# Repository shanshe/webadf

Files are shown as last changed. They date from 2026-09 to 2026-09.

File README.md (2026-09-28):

# webadf

An Amiga disk library that puts a disk in a real Amiga's floppy drive over WiFi.

Two halves that work together:

- **A web app** for keeping Amiga disk images. Upload them, have them identified
  against TOSEC, OpenRetro and Demozoo, organise them into collections, browse and
  edit the files inside a disk, and rewind a disk to any earlier version.
- **A drive replacement.** An RP2350 board plugs into the Amiga's floppy connector,
  behaves like a DD or HD floppy drive, and plays whichever disk you pick in the web app.
  When the Amiga saves, the changes go back to the library.

Pick a disk in the browser, or tap its NFC tag on the drive, and the Amiga reads it.
Workbench 3.1 boots from the board, games load, and saves made on the Amiga show up
in the web app as new versions of the disk.

The rev B board: floppy header J1 on the left, buzzer and OLED in the middle, the Pico Plus 2 W module on the right

*Rev B, designed by Shanshe: 34-pin floppy header, floppy power connector, OLED
display, buzzer, a 4-pin header (J4), and a Pimoroni Pico Plus 2 W.
The KiCad project is in `wifi-floppy/hardware/`; check it with `pnpm hw:verify` before
ordering. The current bench board is rev A2.*

## Features

### Library

- Upload `.adf`, `.adz`, `.dms` and `.hfe`; drop `.lha` and `.zip` archives onto a disk
  to pick files out of them.
- HD (1.76 MB) ADFs are recognised and tagged HD, and are disks like any other: browsed
  and edited in the browser, with full history. Blank HD disks can be made from the
  New disk panel.
- Each unique disk is stored once, however many times it is uploaded.
- Disks are identified against TOSEC, OpenRetro and Demozoo, and grouped into titles
  with cover art, screenshots, publisher, year and type.
- Collections, search as you type, and a layout that works on a phone.
- Create a blank formatted disk: 880 KB or 1.76 MB, OFS or FFS.
- Download any disk as an ADF.

### Inside a disk

- Browse the AmigaDOS filesystem in the browser: files, folders, free space.
- Add, rename, move and delete files and folders; drop a folder from your computer
  onto a disk; drag entries between folders.
- Every change is a new version. The history panel shows what changed in each
  version, lets you browse any old version, and restores one as a new version.
- HFE images (including long-track formats such as Turrican's) play read-only and can
  be extracted to an ADF when every sector decodes.

### The drive

- Set up from a phone: the board opens a WiFi setup page, you enter your network and
  a pairing code from the web app, and it joins your library.
- Mount and eject from the web app, from the drive chips in the header, or by
  tapping an NFC tag.
- Reads and writes on a real Amiga. Saves reach the library as new disk versions,
  including saves made while the board was offline.
- Works as DF0 or alongside a second drive as DF1.
- Plays HD disks: the board tells the Amiga it is an HD drive while an HD disk is in.
  Needs Kickstart 3.0 or later. Playing needs firmware 1.4.1 or later (the web app
  refuses to mount an HD disk on older firmware and says so); saving to an HD disk
  needs 1.5.0 (1.4.x keeps HD write-protected on the board whatever the web app
  says).
- Write protection can be switched from the web app while the disk is in the drive.
- OLED status display: WiFi strength, what it is doing, the disk's name and the
  current track. An activity LED blinks on reads.
- Updates its own firmware from the web app. Releases are signed, a failed update
  falls back to the previous firmware, and the board never updates while a disk is
  in the drive.

### NFC tags

- Tap a tag on the drive to mount its disk. Tapping another tag swaps disks; tapping
  the one already in the drive does nothing.
- Write any disk to a tag from its library card or game page: click the NFC icon,
  tap a tag on the drive, and the result appears in the browser.
- A tag only ever mounts disks from your own library.
- Reader: HW-147C (Si512), on the board's I2C bus next to the OLED.

## How it works

An Amiga floppy drive does not deliver blocks. It hands Paula a raw magnetic flux
stream and the Amiga decodes MFM in software, so a drive emulator has to produce flux
at the right rate, continuously, while the disk spins.

```
  browser  ──mount──▶  web app  ──encodes ADF → MFM──▶  device  ──flux──▶  Amiga
     ▲                    │                                │
     └──── new version ◀──┴── Postgres + blobs     RP2350 + 8 MB PSRAM ◀── NFC tag
```

The server encodes a 901,120-byte ADF into 2,027,536 bytes of Amiga MFM and the board
streams it: PIO emits 2 µs bitcells, DMA restarts each revolution and raises INDEX,
giving 300 rpm. The whole disk lives in PSRAM, so a seek is answered immediately
instead of over the network. The board streams flux rather than ADFs, which lets
flux formats such as HFE use the same path.

An HD disk is the exception. The server sends the board the ADF itself (a small
WFAD header, then 1,802,240 bytes), and the board encodes each track to MFM as the
head reaches it, in about 4 ms, well inside the head's settle time. A PIO program
answers the Amiga's drive-ID read on RDY with the HD ID while an HD disk is mounted.
When the Amiga saves to an HD disk, the board checks all 22 sectors of the written
track, keeps them as ADF bytes, and uploads those bytes as they are.

When the Amiga writes, the board decodes the written tracks, uploads them, and the
server records them as a new version of the disk. Versions are stored as sector
deltas.

## Status

| | |
|---|---|
| Web app: library, collections, identification, search | live |
| Upload `.adf` `.adz` `.dms` `.hfe`; `.lha`/`.zip` onto a disk | live |
| File editing inside a disk, blank disks, drag and drop | live |
| Disk history: browse and restore any version | live, restore verified on hardware |
| Device: setup portal, WiFi, TLS, pairing | verified on hardware |
| Mount and eject from the browser and the drive chips | verified on hardware |
| Reading on a real Amiga (Workbench 3.1, games) | verified on hardware |
| Writing on a real Amiga, saves reach the library | verified on hardware |
| Second drive (DF1) alongside the board | verified on hardware |
| HFE, including long-track (Turrican) | verified on hardware; weak-bit titles not yet tested |
| HD disks, read-only (Kickstart 3.0+) | verified on hardware (firmware 1.4.1, Kickstart 3.1) |
| HD disks: Amiga saves, history, browser editing, blank HD disks | built and host-tested (firmware 1.5.0, not yet published); bench checklist owed (HANDOFF 3ao) |
| Firmware updates from the web app | verified on hardware (current: 1.3.1; 1.4.0 built, not yet published) |
| NFC: tap to mount, write tags from the web | verified on hardware |
| Rev B board | in design (Shanshe) |

## Repository

| Path | What |
|---|---|
| `src/` | the Next.js app |
| `src/lib/adfmfm/` | ADF ⇄ Amiga MFM encoder, verified against Greaseweazle |
| `src/lib/adffs/` | AmigaDOS filesystem reader/writer (OFS/FFS) |
| `src/lib/archive/` | `.lha`, `.zip` and `.dms` decoders, all browser-side |
| `src/lib/hfe/` | HFE parsing, conversion for the board, ADF extraction |
| `src/lib/disk-history/` | sector deltas and the version chain behind history and restore |
| `src/lib/nfc/` | NFC tap and tag-writing rules and storage |
| `wifi-floppy/firmware/` | the RP2350 firmware (pico-sdk ≥ 2.3.0) |
| `wifi-floppy/hardware/` | the board (KiCad) |
| `docs/superpowers/specs/` | design specs, one per feature |
| `HANDOFF.md` | the engineering log: decisions, measurements, bench results |

## Running it

```bash
pnpm install
pnpm dev                  # needs .env.local: DATABASE_URL, BLOB_READ_WRITE_TOKEN,
                          # BETTER_AUTH_SECRET, BETTER_AUTH_URL
pnpm test                 # vitest, pure logic
pnpm e2e                  # playwright, against a real database
```

Firmware:

```bash
export PICO_SDK_PATH=/path/to/pico-sdk        # tag 2.3.0 or later
pnpm firmware:build
pnpm firmware:test                            # host tests, no board needed
pnpm firmware:publish --dry-run               # sign and register a release
```

Write a disk to an NFC tag from the command line:

```bash
pnpm nfc:write "Turrican II disk 1"           # then tap a tag on the drive
```

The setup access point uses the password **`wififloppy`** by default. Set
`PORTAL_AP_PASSWORD` at build time to change it. The pairing code from the web app is
what authorises a board to join a library.

Every push that touches the firmware is built by
[`.github/workflows/firmware.yml`](.github/workflows/firmware.yml), which runs the host
tests and publishes a `.uf2` with a `manifest.json` (version, commit, size, SHA-256).

## Verification

Each layer that talks to hardware or to an undocumented format is checked against an
independent implementation:

| | checked against |
|---|---|
| `pnpm adfmfm:diff` | Greaseweazle's `amigados` codec |
| `pnpm adffs:verify` | `xdftool` |
| `pnpm lha:verify` | the real `lha` binary |
| `pnpm dms:verify` | xDMS, the implementation ours was ported from |

## Licence

- **Software** (the web app, scripts and the wifi-floppy firmware source): [MIT](LICENSE).
- **Hardware** (`wifi-floppy/hardware/`, the board design): [CERN-OHL-P-2.0](wifi-floppy/hardware/LICENSE), the
  permissive open-hardware licence, so anyone can build, modify and sell their own boards. The rev B PCB layout is
  Shanshe's work, licensed this way with Shanshe's agreement; see
  [wifi-floppy/hardware/NOTICE.md](wifi-floppy/hardware/NOTICE.md).
- **Third-party code, the libraries in the firmware image, and acknowledgements**: see
  [THIRD-PARTY-NOTICES.md](THIRD-PARTY-NOTICES.md). The Wi-Fi driver bundled with the Pico SDK is licensed for use
  on Raspberry Pi chips (which this board is).

This project builds on Nano-Tek, OpenFlops, Keir Fraser's FlashFloppy and Greaseweazle, and the other work credited
in the notices file.

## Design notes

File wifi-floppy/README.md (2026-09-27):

# WiFi Floppy Emulator (Amiga) — Pico 2 W

Gotek-style drive replacement that streams pre-encoded MFM tracks over
WiFi from your ADF webservice instead of reading a USB stick.

## Contents
- `hardware/schematic.svg` — full schematic (net names match the PCB)
- `hardware/wifi_floppy.kicad_pcb` — placed **and routed** 2-layer board,
  45°-only corners, B.Cu ground pour. Open directly in KiCad 7/8 and
  press `B` to refill the zone.
- `hardware/generate_pcb.py` — the generator that produced the board,
  including a DRC-lite checker (crossings, clearance ≥0.15 mm, 45° rule).
  Currently passes with 0 violations.
- `firmware/` — pico-sdk project (RP2350 / `PICO_BOARD=pimoroni_pico_plus2_w_rp2350`,
  pico-sdk >= 2.3.0 required — see "Firmware build requirements" below).

## Design
- **J1** 34-pin, Amiga internal pinout: pin 2 = /DSKCHG, pin 34 = /RDY
  (unlike PC drives where 34 is DSKCHG).
- **U2 74LVC541A** buffers all host-driven lines into the Pico
  (3.3 V part, 5 V-tolerant inputs). J1→A1..A8→GP2..GP9 are mapped in
  physical order, so the input routing is completely crossing-free.
- **Q1–Q6 BSS138** give open-drain outputs. They invert: **GPIO high =
  bus line pulled low**. Firmware and the PIO program already account
  for this (`OUT_ASSERT`).
- **Power**: 5 V from the Berg connector through D1 (SS14) into VSYS.
  Safe to co-power over USB while bench testing.
- PIO `flux_out` emits 2 µs bitcells (8 PIO cycles @ 4 MHz, clkdiv 37.5
  from 150 MHz), 750 ns read pulses; DMA restarts per revolution and
  raises a ~2 ms INDEX pulse at the wrap → exactly 300 rpm timing.
- 16-track LRU cache (~205 KB) + neighbour prefetch; a track is ~12.7 KB
  so a LAN fetch lands well inside a seek's settle time.

## Track server protocol — SUPERSEDED

**This section describes a protocol the firmware no longer speaks.** `http_fetch.c`,
which implemented `GET /tracks/<n>`, was deleted in plan 4a. The real device contract is
`GET /api/device/poll` (long-poll for desired state), `GET /api/device/image/<sha256>`
(the whole disk as a `WFMF` container, format defined in `image_loader.c`), and
`POST /api/device/status`. See `INTEGRATION.md` and
`docs/superpowers/specs/2026-08-29-device-plane-disk-change-design.md` §10 for the actual
contract. Kept below only as a historical note; do not implement against it.

```
GET /tracks/<n>        n = cyl*2 + side  (0..159)
 -> 200, body = [u32 LE bit_count][raw MFM bytes]
POST /tracks/<n>       (write-back, not implemented yet)
```
Encode server-side (ADF → Amiga MFM incl. 0x4489 syncs, odd/even split);
the firmware just plays bits. Suggested next step for the webservice.

## DSKCHG / RDY
`src/dskchg.c` re-implements FlashFloppy's Amiga-interface behaviour
(chgrst=step semantics, motor-edge drive-ID shifter, spin-up delay).
It's a from-scratch implementation of the observable behaviour, not a
code port. FlashFloppy is Keir Fraser's (https://github.com/keirf/flashfloppy,
Unlicense) and is credited in ../THIRD-PARTY-NOTICES.md.

## Firmware build requirements

- **pico-sdk >= 2.3.0.** `hardware_psram` (and this board's
  `PICO_PSRAM_CS_PIN`/`PICO_PSRAM_SIZE_BYTES` board-header support) landed in
  pico-sdk PR #2919, after the 2.2.0 release; 2.3.0 is the first tag that has
  it. `CMakeLists.txt` checks `PICO_SDK_VERSION_STRING` and fails the
  configure step with an explanation if `PICO_SDK_PATH` points at anything
  older.
- **`brew install arm-none-eabi-gcc` is not sufficient** — that formula ships
  GCC and libgcc but no newlib, so linking fails with `cannot find -lg`/`-lc`
  on the very first target. Use the official ARM GNU Toolchain instead (the
  `gcc-arm-embedded` cask, or the equivalent tarball from
  developer.arm.com/downloads/-/arm-gnu-toolchain-downloads) and make sure
  its `bin/` is on `PATH` ahead of any homebrew `arm-none-eabi-*` shims.
- **`PORTAL_AP_PASSWORD` must be set in the environment (plan 4b).** It becomes the WPA2
  PSK for the provisioning access point (see "Provisioning a board" below); CMake's
  configure step fails on purpose if it is unset or empty, because an invalid WPA2 PSK
  cannot be reported back to a console-less board at runtime. The full build command:

  ```bash
  export PATH="/Applications/ArmGNUToolchain/15.3.rel1/arm-none-eabi/bin:$PATH"
  export PORTAL_AP_PASSWORD=<your AP password>
  pnpm firmware:build
  ```

## Provisioning a board (plan 4b)

**Steps 1-3 are verified on hardware as of 2026-09-10; steps 4-5 are not.** The AP
comes up, iOS raises the sign-in sheet on its own, and the form renders at
192.168.4.1. Everything from pressing Save onwards — teardown, association,
registration — has still only ever run against the host suite. See "Honest caveats"
below.

A board with no WiFi credentials stored in flash — or one that has just failed to associate
three times in a row — raises its own WPA2 access point named `wifi-floppy-XXXX`, where
`XXXX` is the last two octets of the board's MAC address (so several boards on a bench stay
distinguishable). To provision it:

1. **Mint a pairing code in webadf.** From the web app, generate a device pairing code for
   the board (single-use, 10-minute TTL — if it expires before step 4, generate a new one).
2. **Join `wifi-floppy-XXXX`** from your phone or laptop, using the WPA2 password baked into
   that board's firmware image at build time (`PORTAL_AP_PASSWORD`, above — whoever built
   the firmware knows it).
3. **Open any page** in a browser on that device. The board's DNS responder answers every
   query with its own address and the HTTP server redirects every path to `/`, so a phone's
   captive-portal probe should bring the config form up on its own; if it does not, browse to
   `http://192.168.4.1/` directly.
4. **Enter three fields**: your real WiFi network's SSID, its password, and the pairing code
   from step 1. Submitting does not commit anything yet — the board drops its own AP,
   attempts to associate with what you typed, and only writes the credentials to flash on
   success. Your phone will briefly lose the `wifi-floppy-XXXX` network while this happens.
5. **On success**, the board joins your real network and proceeds to register with webadf
   using the pairing code; the AP does not come back. **On failure** (wrong password, or the
   network was not found — the form distinguishes the two), the AP returns with the reason
   and the form is ready to try again; re-enter all three fields, since none are echoed back.

**Recovery without reflashing.** If webadf later reports the board's token as revoked or the
device row is deleted, the board erases its stored token and returns to step 1 automatically
— generate a fresh pairing code and repeat steps 2–5. The same is true of a rejected
(expired or already-used) pairing code: the board returns to the portal rather than retrying
the dead code forever.

## Watching the log

```bash
tio /dev/cu.usbmodem*          # brew install tio; it reconnects across reboots
```

Output looks like this — uptime in seconds.milliseconds, then which core:

```
[    0.002] c0 wifi-floppy boot: pimoroni_pico_plus2_w_rp2350
[    0.481] c1 radio up (RM2)
[    0.494] c1 portal: raising AP
[   34.117] c0 MOTOR        a=1 b=0
[   34.119] c0 SEL          a=1 b=0
[   34.226] c0 STEP         a=1 b=0
[   34.229] c0 TRACK-SERVED a=2 b=101376
[   34.431] c0 INDEX        a=3168 b=0
```

Two entry points, and the difference is load-bearing. `wf_logf()` formats with
`vsnprintf` and is for core1 and core0's loop. `wf_trace()` takes an integer event code
and two integers — no formatting, no format string — so it is legal inside the flux DMA
handler, where a flash-resident string would not be. `wf_trace` is placed in SRAM with
`__not_in_flash_func` for the same reason `dma_irq` is.

**core0 drains, core1 only produces.** core0's service loop already sleeps 1 ms per
iteration and the bit-level work is PIO and DMA, so it has the slack to write to USB;
core1's loop blocks for tens of seconds inside a long-poll and would strand every core0
trace behind it. A useful consequence: a core1 hang still gets its last line out, which
is why `cyw43_arch_init` failing logs before it spins forever.

The ring holds 63 records (~7 KB of SRAM). When it fills it **drops newest and counts
them**, then prints `-- N record(s) dropped --` once the backlog clears. It never blocks
a producer: a logger that stalls the floppy service loop to report on the floppy service
loop would be worse than no logger. `PICO_STDIO_USB_STDOUT_TIMEOUT_US` is set to 1 ms in
`CMakeLists.txt`, against an SDK default of 500 ms, so an unattended USB port cannot
stall that loop either.

UART stdio stays off and must stay off: GP0 and GP1 are INDEX and CHNG on this board, so
enabling it would drive the floppy bus.

## Honest caveats
- **First run on real hardware: 2026-09-10.** A rev A2 board, partially populated
  (J1, J2 and U1 only), flashed with `wifi_floppy.uf2` and powered over USB. What that
  exercised, end to end, on real silicon:
  - the RP2350 boots the image, reaches `main()`, and launches core1
  - `cyw43_arch_init()` succeeds — the **RM2 radio works over SPI**, the single
    largest never-before-run piece
  - the AP comes up: `wifi-floppy-6A38`, WPA2-AES, SSID built from the chip's own MAC
  - **DHCP hands the phone an address, the DNS responder answers, and the HTTP server
    serves the form** at `192.168.4.1`
  - **iOS's captive-portal probe raises the sign-in sheet on its own** ("Wi-Fi med
    tilmelding"), which was explicitly on the unverified list
  - the page's `28:cd:c1:19:6a:38` and the SSID's `6A38` agree, so `main.c`'s
    `mac_address_string()` and `portal_net.c`'s SSID construction cross-check
  - no re-enumeration of the USB CDC device over several minutes: no crash loop

  **Still not run on hardware:** everything past pressing Save. AP teardown and the
  transition back to station mode, association with a real network, the confirmation
  page arriving before the AP drops, DHCP lease renewal after teardown, the 3-slot
  lease pool under real phone behaviour, Android's captive-portal probe, TLS, SNTP,
  device registration, and the whole floppy side — PIO cycle counts, DMA, PSRAM image
  load, bus timing — which remain desk-checked only. See
  `docs/decisions/2026-08-31-device-portal-rulings.md`'s hardware-only list for the
  full set, which plan 5 owns closing.
- **Console logging exists as of 2026-09-10 (`src/wf_log.c`), but has not itself run on
  hardware.** Before it, the firmware wrote nothing at all: `stdio_init_all()` brought up
  the CDC device so a port appeared and a terminal attached, but there was not one
  `printf` in `src/`, and listening returned zero bytes. See "Watching the log" below for
  how to use it. Host-tested (74 checks) and cross-built clean; every line it prints on a
  real board is still unobserved.
- It compiles (`pnpm firmware:build` produces `firmware/build/wifi_floppy.uf2`) and has
  a green host suite (`pnpm firmware:test`, 506 checks across 13 binaries, plain C under
  clang). Treat anything not covered by a host test or by the hardware run above as
  unverified.
- Write support is a skeleton: flux capture PIO exists, MFM decode and
  POST are TODO. WPROT is asserted by default until that lands.
- The board passes my generator's DRC-lite, but run real KiCad DRC and
  sanity-check footprints (Pico row spacing 17.78 mm, SOIC-20W, SOT-23)
  against your parts before ordering.
- No mounting holes; outline is a plain 96×62 mm rectangle. Reshape to
  3.5"-drive dimensions if you want it inside a Gotek/drive bay.
- Board is 2-layer; several signals ride the B.Cu plane, which slices
  the pour locally. Fine at 500 kHz MFM rates, but keep the pour filled.

## PSRAM revision (Pimoroni Pico Plus 2 W)

U1 is now specified as a **Pimoroni Pico Plus 2 W** (RP2350B, 16MB flash,
8MB PSRAM, RM2 radio). It keeps the Pico footprint and pinout, so the PCB is
unchanged electrically - only the module value differs.

PSRAM is the disk. The image is pulled in **one bulk transfer at mount**
(`image_loader.c`) and the floppy bus is served entirely from RAM after
that - the read path contains no network call at all.

| where | size | role |
|---|---|---|
| SRAM double buffer | ~26 KB | only DMA source for the flux PIO |
| PSRAM disk image | 2.03 MB | the whole disk, 160 x 13 KB slots |

**The route below is superseded** — the firmware fetches
`GET /api/device/image/<sha256>` (keyed by digest, not an integer id; see
`INTEGRATION.md` and disk-change spec §10), but the `WFMF` container body format
itself is current and matches `image_loader.c`:

    u32 magic 'WFMF'   u32 version=1   u32 track_count   u32 reserved
    per track: u32 bit_count, ceil(bits/8) bytes, padded to 4 bytes

RDY and CHNG stay deasserted until the whole image is in PSRAM, so a slow or
failed load looks like "no disk yet" to the Amiga rather than a drive that
stalls mid-track. A track missing from PSRAM is a fault, not a cache miss:
`track_cache_get()` returns NULL and nothing is streamed.

The loader parses the blob incrementally as TCP chunks arrive, writing
straight into PSRAM (a 2 MB image never fits in SRAM). It was tested on the
host against randomly-chunked input at real track sizes, plus malformed
input: oversized tracks and bad magic are rejected without overflowing a slot.

Notes / still to verify on hardware:

* **GP0/GP1 are the board's default UART pins** and carry INDEX and CHNG here.
  `pico_enable_stdio_uart(... 0)` is set; stdio goes out over USB. Do not
  re-enable UART stdio or it will drive the floppy bus.
* The flux DMA never reads PSRAM directly - a QMI cache miss contending with
  XIP can add latency at a 2 us bitcell. Tracks are copied PSRAM -> SRAM.
* **Antenna keepout position is still an assumption, and the PIM726 documents
  do not settle it.** A schematic carries no placement, and the "Pins and
  Dims" sheet's board illustration is not something to read a fab decision
  off. What the keepout currently claims, so it can be checked against a
  module in hand: it spans the module's full 21 mm width and the last 5.4 mm
  of its 51 mm length at the **non-USB end** - the pin 19-22 end, GP14-GP17.
  If the RM2's antenna is anywhere else, there is ground plane under it.
  Costs nothing to keep: GP14-GP17 are unused on this board, so the keepout
  is only wrong if it is in the wrong *place*, never merely expensive.
* ~~Confirm GP0-GP17 map to the same physical castellations on the RP2350B
  board as on the Pico 2 W.~~ **CONFIRMED 2026-09-09** against the PIM726
  schematic (sheet 3/3, "Output headers"). The Plus 2 W's header is the
  standard Pico header pin for pin: pin 1 = GP0 through pin 22 = GP17, with
  GND on 3/8/13/18/23. The only difference is that pins 6 and 7 are labelled
  `GP4_SDA` and `GP5_SCL` because they also feed the QW/ST connector - same
  GPIOs, alternate function. Every U1 signal this board uses lands where it
  was assumed to.
* Write-back path is still a skeleton: PSRAM now has TRK_DIRTY state and
  `psram_image_next_dirty()` for a flush walker, but nothing calls it yet.

## J1 floppy header - construction

J1 is a **male 2x17 through-hole pin header on 2.54 mm pitch** (both axes),
which is what a standard 34-way floppy ribbon with female IDC sockets on each
end plugs onto - same as a real 3.5" drive or a Gotek.

* Numbering is standard IDC dual-row: pin 1 and 2 adjacent across the rows,
  odd pins down one column, even down the other.
* All odd pins (1..33) are GND, matching the ribbon's alternating ground
  returns. Signals are on the even pins.
* Pin 1 now has a **square pad**, plus a silkscreen body outline and a
  chevron marker outside pin 1, so the red stripe end is unambiguous.
* Pads 1.7 mm with 1.0 mm drill - correct for the usual 0.64 mm square posts.

**Shrouded header is not a drop-in.** A keyed 2x17 IDC box header has a
10.16 mm body, which overhangs the FET drain pads by ~1.35 mm. To fit one,
the Q1-Q6 column must move about 2 mm east, which also pushes the input
routing channels. The plain header is what most drives use, so rev B keeps
it; polarity relies on the pin-1 markings and the cable's red stripe.

## Revision history - rev B is current

| rev | state |
|-----|---|
| A | fabricated, **scrap** - every layer mirrored, and four SOT-23s reflected |
| A2  | fabricated, **usable with a caveat** - correct except that the ground pour runs under the RM2 antenna |
| B | **current**, not yet fabricated - A2 with the antenna keepout at the right end; copper, mask, drill and outline are byte-identical to A2 |

### Rev A2 errata - rev A boards are scrap

The first batch (rev A) came back from JLCPCB mirrored and cannot be used.
Two independent bugs, both now fixed and both now covered by
`hardware/verify_board.py`, which must be run before any future fab order.

**1. Gerber Y axis.** KiCad's coordinate system has Y increasing downward;
Gerber and Excellon have Y increasing upward, and KiCad negates Y when it
plots. `export_gerbers.py` wrote coordinates straight through, so every
layer was reflected. The renderer used the same Y-down convention, so the
preview looked correct and the verification compared the Gerbers against an
equally wrong-handed source - self-consistent, and self-consistently
mirrored.

**2. SOT-23 gate/source.** Q1, Q2, Q3 and Q6 were reflections of the
canonical KiCad SOT-23 land pattern - gate and source swapped - so a real
part would have had its gate on the GND pad and never switched. Only Q4 and
Q5 were right. Independent of bug 1; it would have shipped either way.

Fixing 2 moved the gate and source pads, which made Q3's gate pad overlap
Q4's source pad, so Q3 moved 0.6 mm north and its drain now jogs to J1 row
13 the way Q2 and Q5 already did. The INDEX, TRK0, RDY and CHNG gate routes
were re-run to suit.

`verify_board.py` now checks every footprint against the canonical KiCad land
pattern (rotation = fine, reflection = fail) and confirms the Gerber pads sit
at the mirrored Y of the .kicad_pcb. Regression-tested against the old broken
export: it reports 118/122 pads at un-mirrored Y and fails.

**A2 follow-up: antenna keepout was at the wrong end.** The rev A2 boards
were fabricated with the ground pour void over U1 pins 1/2/39/40 instead of
19/20/21/22 - the opposite end of the module. Cause: `export_gerbers.py`
flipped Y for pads, traces, silk, outline and drill, but not for the keepout
zone polygon, so the void mirrored away from the antenna. The pour audit
missed it because it used the same unflipped polygon on both sides of the
comparison - self-consistent again. Fixed, and `verify_board.py` now asserts
the keepout covers U1 pins 19-22 - reading copper out of the emitted `.GBL`
rather than re-deriving the void from the exporter, so the check cannot agree
with the exporter's mistake the way the last one did. Regression-tested both
ways: it fails on the rev A2 `.GBL` (25/25 sample points copper under the
antenna) and passes on the current one (0/25).

Consequence for the rev A2 boards in hand: they are electrically fine (all 27
GND pads still bond, no signal pad is affected) but there is ground plane
under the RM2 antenna and a harmless void near pins 1/2. Build one and check
signal strength before respinning - the whole-image PSRAM load means WiFi only
has to work at mount time.

### Rev B

The corrected files are **rev B** and have not been fabricated. Copper, mask,
drill and outline are byte-identical to rev A2 - `.GTL`, `.GTS`, `.GBS`, `.GKO`
and `.TXT` all unchanged - so an assembled rev A2 board remains a valid bring-up
target and nothing in the BOM changes. Two files differ: `.GBL` for the keepout,
and `.GTO`, because rev B is the first revision whose silkscreen will print.

**Rev B is marked.** The board says `WIFI FLOPPY REV B` on the silkscreen and
carries its reference designators; rev A and rev A2 have neither, so an unmarked
board is one of the older two. Which of those it is you tell from the pour void:
on A2 it sits at the USB end of U1, on B at the opposite end.

### Rev A and rev A2 have outlines but no lettering

**Corrected 2026-09-09 from a photograph of an assembled rev A2 board.** An
earlier version of this section said the silkscreen never printed at all and
blamed the fab for stripping it. That was wrong, and it was wrong in the
direction that flatters the diagnosis: I inferred it from a spec table instead
of from the board. J2's and U1's body outlines are plainly legible on a real
board, at 0.12 mm. Two separate things are true:

1. **The exporter dropped everything that was not an `fp_line`, and that is why
   there is no lettering.** All 13 reference designators, the antenna-keepout
   label and U2's pin-1 dot never reached the `.GTO` at all - silently, because
   nothing counted what it skipped. `export_gerbers.py` now renders text through
   `stroke_font.py`, a single-stroke vector font, and draws circles.
2. **Every silk feature was also below the fab's published minimum**, which is a
   real DFM violation even though it printed. JLCPCB's minimum silkscreen line
   width is 6 mil (0.1524 mm); the outlines were 0.12 mm and the J1 chevron
   0.15 mm, so all 17 features were under it. They came out this time. A layer
   that prints only because the fab was lenient is not one to ship again, so rev
   B draws silk at 0.2 mm and text at 1.0-1.5 mm.

Neither was visible to any check, which is the third time something wrong in the
fab output got there because nothing was looking at it. `verify_board.py` now
reads feature widths back out of the emitted `.GTO` and fails on anything below
the fab minimum, and `export_gerbers.py` reports any legend stroke that lands
within 0.15 mm of a pad. Designator placement was moved to suit: the FET column
is on a 3.14 mm pitch, so Q1-Q6 label to the east rather than above.

### Orienting the parts

D1 is the only part you can silently fit the wrong way round, so rev B marks
it: a body outline closed at the cathode end, drawn with a heavier bar than
the sides. **The SS14's banded end goes to that bar** - pad 1, the pad whose
trace runs the long way up the board, away from J2. Pad 2 is the anode, fed by
the +5V run that comes along the bottom edge from J2.

Pad 1 is the cathode by what KiCad's own `D_SMA` draws, not by convention: its
`F.Fab` layer puts the diode symbol's bar on the pad-1 side with the triangle
pointing at it, and its `F.SilkS` outline closes that end. The netlist agrees -
pad 1 is `VSYS`, pad 2 is `+5V`, and current runs anode to cathode. Reversed,
the board simply will not power from the floppy connector while still working
over USB, which is an annoying thing to debug.

Everything else is keyed:

| part | how you orient it |
|---|---|
| J1, J2, U1 | square pad 1 (J1 also has the chevron). U1 matters - a 2x20 header footprint is symmetric, so the module fits rotated 180 degrees |
| U2 | pin-1 dot on the silkscreen |
| Q1-Q6 | no marking, and none needed: SOT-23 has two pads one side and one the other, so it cannot land rotated |
| C1, C3 | ceramic, not polarised |

**Still unconfirmed:** that the RM2's antenna is at the pin 19-22 end at all.
That is inherited from the CYW43 Pico 2 W and has never been checked against a
PIM726 in hand. `verify_board.py` enforces the assumption; it cannot validate
it. Confirm before ordering rev B, because moving the void is the only thing
rev B does.

Component orders are unaffected - every part in the Mouser order is still
correct for rev A2 and for rev B.

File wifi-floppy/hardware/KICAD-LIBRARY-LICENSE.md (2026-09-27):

# KiCad library parts in this directory

The footprints in `wifi-floppy-lib.pretty/` and the symbols in `wifi-floppy-lib.kicad_sym` include parts copied from
the official KiCad libraries (https://gitlab.com/kicad/libraries), © KiCad Library Team.

Those library files are licensed under **CC-BY-SA 4.0 with the KiCad library exception**
(https://www.kicad.org/libraries/license/). In short: the exception says that using these symbols and footprints in
a design, and distributing the design's output (schematics, PCB layouts, Gerbers, BOMs), does not by itself put the
design under CC-BY-SA. Changes to the library files themselves remain under CC-BY-SA 4.0.

The board design itself (schematic, PCB, production files) is licensed separately; see the Licence section of the
repository README.

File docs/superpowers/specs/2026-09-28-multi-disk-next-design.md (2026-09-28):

# Multi-disk titles: "Next disk", a Next-disk NFC card, and preloading — design

Date: 2026-09-28. Status: approved in conversation (four sections), awaiting spec review.
Backlog entries this closes: HANDOFF "Multi-disk games while playing" (ideas 1 and 2 only) and "An NFC card for
swapping disks within the mounted game or utility".

## 1. Intent

**The operator asked for:** a way to advance to the next disk of a multi-disk game or utility while it is running,
and a dedicated NFC card that, tapped on a board, advances that board to the next disk of whatever title is
mounted, instead of naming one disk.

**Agreed in conversation:**
- Scope is backlog ideas 1 and 2: a "Next disk" action plus preloading the next disk into the idle slot. Two-drive
  (DF0 + DF1) emulation and automatic "insert disk 2" detection are out of scope.
- One universal card (option A): it carries no disk and no org. Any Next-disk card works on any board; the board's
  own org and mounted title bound what it can do. After the last disk it wraps to disk 1.
- The server decides what "next" is (approach 1); the board only preloads what the server names.
- Writing a Next-disk card is a button on the **Devices page**, not on a disk (it is org-wide and rare).
- A tap while the board is still uploading saves is accepted; the swap is queued behind the upload.

**Success:** on the bench, a Next-disk tap on a preloaded two-disk title swaps in under 1 s (today ~5 s per
fetch), the Amiga sees an ordinary eject + insert, and no save is lost.

**Measured 2026-09-28 (live DB, all orgs):** 14 titles have more than one disk (2 to 7 disks); none has a gap in
its disk numbers; one has two disks with the same disk number.

## 2. The next-disk rule (server, pure)

`nextDisk(disks, current, board)` in `src/lib/next-disk.ts`, no I/O, unit-tested.

- **Input:** the disks of the current disk's title in the board's org (`id`, `diskNo`, `createdAt`, and what the
  board-capacity check needs), and the current disk id.
- **"Current" is the WANTED disk** (`devices.desiredDiskId`), not the mounted one, so a second tap during a swap
  moves one further instead of repeating the same swap. With no wanted disk it falls back to the mounted disk.
- **Duplicates:** disks sharing a `diskNo` collapse to the lowest `id`, consistently (amended 2026-09-28: `disks` has no timestamp column, plan R5). If the
  current disk is a non-canonical duplicate, "next" still counts from its `diskNo`.
- **Capacity:** a disk the board cannot hold (the existing mount check: HD on a board that cannot take HD, tracks
  longer than its reported `trackMaxBytes`) is skipped.
- **Result:** the lowest `diskNo` above the current one; after the highest, the lowest (wrap).
  - `{ kind: 'disk', disk }` when the result differs from the current disk;
  - `{ kind: 'single' }` when the title has only one usable disk;
  - `{ kind: 'nothing_mounted' }` when there is no current disk, or it no longer belongs to a title.

## 3. Server

### 3.1 Tap: `POST /api/device/tap`

- The body becomes `{ diskId } | { action: 'next' }` (zod union). The disk-id branch is unchanged.
- `action: 'next'` runs through the same guard as a disk tap: the 1 s burst rule (`TAP_MIN_INTERVAL_MS`,
  `lastTapAt`), then `nextDisk`, then the same mount step a disk tap uses (`setDesired`, version bump).
- **Outcomes:** `mounting` (with `diskNo`, `diskCount`), `single`, `nothing_mounted`, `ignored`. Always 200, as
  today (D4).

### 3.2 Web: `POST /api/devices/[id]/next`

- Session-authenticated; the device must belong to the caller's org (the same checks as
  `/api/devices/[id]/mount`).
- Runs `nextDisk` and `setDesired`. Returns `{ outcome, diskNo?, diskCount? }`, using the same outcomes as 3.1 except
  `ignored` (no burst rule from the web).

### 3.3 Poll: the `next` field

- Every poll response that carries `desired` also carries `next`: `{ diskId, sha256, diskNo, diskCount, … }` in
  the same shape as `desired`, or `null` when the rule gives `single` or `nothing_mounted`.
- It is computed when the poll is answered, so a browser edit to the next disk (new blob, new sha256) shows up in
  the next poll. `next` itself is not stored. The only migration in this feature is the three columns in 3.4
  and 3.5.
- Old firmware ignores the unknown field.

### 3.4 Writing a Next-disk card

- `POST /api/nfc/write` accepts `{ kind: 'next', deviceId? }` alongside `{ diskId, deviceId? }`. The pending write
  on the device row records the kind in a new `nfc_write_kind` column (`'disk' | 'next'`, default `'disk'`), added
  in the same migration as 3.5. The poll's `nfcWrite` instruction gains `kind: 'disk' | 'next'`; for `next`,
  `diskId` is absent.
- Everything else is reused unchanged: the 2:00 TTL, the cursor, cancel and read-back.

### 3.5 Status report

- The board reports its preload state as `preload: { sha256, state: 'loading' | 'ready' } | null` in
  `/api/device/status`.
- It is stored on the device row next to the existing live-state columns (one migration: `preload_sha256`,
  `preload_state`).
- Firmware too old to report it leaves both columns NULL.

## 4. Firmware

### 4.1 Tag payload

- WFDK layout unchanged. A Next-disk card is **version 2**: `[0..3] "WFDK"`, `[4] 2`, `[5] 4`, payload ASCII
  `next`, CRC as for v1.
- `nfc_tag_decode` gains the result `NFC_TAG_NEXT`. `nfc_tag_encode_next()` writes it.
- Firmware older than this rejects version 2 as `NFC_TAG_BAD_DATA` and does nothing, which is the safe failure.

### 4.2 Tap

- `NFC_TAG_NEXT` posts `{"action":"next"}` to the tap endpoint.
- The existing 3 s absence rule still applies, so a card left on the reader fires once.
- The OLED shows the outcome for about 2 s:
  - "Disk N of M" (mounting);
  - "Single disk";
  - "No disk";
  - "Offline" (the request failed; nothing is queued locally, because the server decides).
- A tap while dirty tracks are pending is sent normally. The swap it causes waits behind the upload (4.4), and the
  OLED shows "Saving…" until then.

### 4.3 Preloading

- **When:** the poll names `next`, its sha256 differs from what the idle slot holds, and the board is idle:
  - no fetch in progress;
  - **no dirty or unsent tracks** (the idle slot may be needed while a save is outstanding);
  - no firmware stage in progress.
- **How:** the existing streaming loader (`image_parse_begin` on `psram_inactive_slot()`), identical to a fetch
  except that it **does not call `psram_publish_slot()`**. On a complete, verified body it records
  `preload = { slot, sha256, ready }`. An incomplete body leaves no preload record, with no retry storm: the next
  poll retries under the existing backoff.
- **Invalidation (amended 2026-09-28):** `next: null`, an eject, or any fetch that reuses the idle slot drops the
  record. A *changed* `next` does not drop it on arrival: the poll that swaps to B also names C as next, and
  dropping B's record then would make every Next tap a full fetch. The record is replaced when the new next is
  preloaded, and the swap-time sha256 comparison means a stale record can never be published.
- **Never touches the active slot.** Rule 2 of `device_client.c` (no diskless gap) is unaffected.
- HD disks preload in their ADF_HD slot kind exactly as a normal HD fetch does.

### 4.4 Swap

- When `desired` changes:
  - if `preload.ready` and `preload.sha256 == desired.sha256`, publish that slot at once (the normal publish path:
    CHNG eject, then insert);
  - otherwise fetch as today.
- Either way, the existing write-back rule holds: a swap waits until disk N's dirty tracks are uploaded.
- After the swap, the slot that held disk N is the idle slot, and the next poll's `next` preloads N+1 into it.

### 4.5 Card writing

- When the poll's `nfcWrite.kind` is `next`, the board writes the v2 payload and reports the read-back through the
  existing tap-write report.

## 5. Web app

- **Drive menu** (the floppy chip beside the top menu, and the device card on the Devices page):
  - A "Next disk: Disk N of M" item, shown only when the mounted title has more than one usable disk. On the last
    disk it reads "Next disk: Disk 1 of M (wraps)". It calls 3.2.
  - A preload line (amended 2026-09-28): "Disk N ready (instant swap)" when the preloaded sha256 is the next
    disk, "Disk N loading…" while the board reports loading, and "Disk N not preloaded yet" for any other
    reported state. It is hidden when the board does not report preload state (firmware before 1.6.0). The card
    shows it only once the board has converged, like the chip.
- **Devices page header:** a "Write a Next-disk card" button, shown when any board reports an NFC reader and runs firmware 1.6.0 or newer
  (it reports preload state; older boards cannot write the card, and the write route refuses them with 409). It
  opens the existing write dialog with the board picker. The disk picker is replaced by the line "This card
  switches whatever is mounted to its next disk."
- Disk and title pages are unchanged; each disk's own NFC button still writes that disk.

## 6. Edge cases

| Case | Behaviour |
|---|---|
| Duplicate `diskNo` in a title | Oldest counts; the other is still mountable directly |
| Two taps more than 1 s apart | Each advances one disk (counted from the wanted disk) |
| Two taps less than 1 s apart | Second is `ignored` |
| Tap during a swap | Counts from the wanted disk, so it goes one further |
| Next disk edited in the browser after preloading | New sha256 in the poll; stale preload dropped; never swapped to old bytes |
| Board cannot hold the next disk (HD on a DD-only board, long tracks) | Skipped by the rule |
| Tap while saves are uploading | Accepted; swap queued behind the upload; OLED "Saving…" |
| Wi-Fi down at tap | Nothing changes; OLED "Offline" |
| Firmware update waiting for idle | A preload in progress counts as not idle; a completed preload does not |
| Old firmware and a v2 card | `BAD_DATA`, ignored |
| Old firmware and a poll with `next` | Field ignored; swaps fetch as today |

## 7. Testing

- **vitest:**
  - `nextDisk`: wrap, duplicates, single, nothing mounted, wanted-over-mounted, capacity skip;
  - tap route with `action: 'next'` (including the burst rule);
  - `/api/devices/[id]/next` including org scoping (another org's device is 404);
  - the poll's `next` field (present, null, and following a sha256 change);
  - `nfc/write` with `kind: 'next'`;
  - the status route's `preload` field.
- **Firmware host tests:**
  - v2 encode/decode, and v1 unchanged;
  - preload bookkeeping: start conditions, including none while dirty; invalidation; swap-from-preload versus
    fetch; a swap queued behind a pending upload.
- **Playwright:**
  - the drive menu item, its label and the wrap;
  - the preload line in both states;
  - the Devices page button and dialog;
  - the same at 390 px.
- **Bench (operator):**
  - swap time from preload (under 1 s) versus fetch (~5 s);
  - a mid-game card tap on a real two-disk title;
  - a tap during a save upload;
  - writing a card from the Devices page;
  - an old-firmware board ignoring a v2 card, if one is available.

## 8. Out of scope

- DF1 emulation (backlog idea 3).
- "Insert disk 2" detection (idea 4).
- A Previous-disk card.
- Per-title cards.
- Buzzer feedback: comes with the buzzer resistor order.

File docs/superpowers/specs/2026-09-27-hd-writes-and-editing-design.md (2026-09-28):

# HD disks: Amiga writes, full history, browser editing, blank HD disks — design

Status: approved in conversation 2026-09-27, section by section. Written spec awaits operator review.
Follows `2026-09-26-hd-floppies-read-only-design.md` (read-only HD, firmware 1.4.1, verified on hardware 2026-09-27).

## 1. What this is for

HD disks (1,802,240-byte ADF, 22 sectors/track, 160 tracks) become full citizens: saves made on the Amiga reach the
library as new versions exactly as DD saves do (including saves made while the board is offline); the history panel
shows file-level "what changed", browsable old versions and restore; HD disks can be edited in the browser; and blank
HD disks can be created.

Done means: on the bench (A5000, Kickstart 3.1) an Amiga save to an HD disk appears as a new version whose files can be
browsed; a large multi-track copy verifies; offline saves arrive; restore works; DD behaves exactly as before.

## 2. Decisions taken (operator, 2026-09-27)

| Decision | |
|---|---|
| History for HD is full (option A): file-level diff, browse old versions, restore | operator |
| Browser editing and blank HD disks are in this project, not a follow-up | operator took the recommendation |
| Blank HD disks get a plain DD/HD choice beside OFS/FFS in today's create control; the mobile-friendly redesign of that menu stays on the backlog | this design |
| HD disks stay write-protected by default, like every disk | this design |
| Older boards (1.4.1) keep forcing HD read-only on their own; documented, no capability flag | this design |
| Out of scope: HD in `.dms`, HD HFE | unchanged |

## 3. What the code does today (mapped 2026-09-27)

Firmware: capture window `FLUX_CAPTURE_MAX_MS 400` (= one HD revolution, so HD writes are silently abandoned); capture
buffer `MFM_BUF_BYTES 16384` (~65 % of an HD track); decoder `MFM_SECTORS 11`, `uint16_t found`, `sector_id >= 11`
rejected; `write_back_verdict` completeness `0x7ff`; `psram_image_store` refuses `SLOT_KIND_ADF_HD`; the uploader
re-decodes tracks through `psram_image_read` (refuses ADF_HD) and posts 5,632-byte bodies; `write_back_wprot` forces
WPROT for HD. Server: `isTrackUpload` requires 5,632 bytes (and runs before the HD refusal, so HD gets 400);
`overlayTracks`, `delta.ts`, `chain.ts materialise`, `history.ts` hard-code 901,120 / 1,760 sectors; `restore.ts`,
`disk-write.ts`, `volume-name`, `files/*` and the write-protect PATCH refuse HD; `readDesired` forces `writeProtected`
for HD. adffs: `BLOCK_COUNT = 1760`, `ROOT_BLOCK = 880` hard-coded; `readVolume` returns `not-adf` for any other size.

## 4. Firmware

### 4.1 Capture
- `FLUX_CAPTURE_MAX_MS` 400 → **800** (two HD revolutions).
- `MFM_BUF_BYTES` 16,384 → **28,672** (one HD track, 25,336 bytes, plus margin). ~12 KB more static RAM; the heap
  low-water after TLS was 69,632 bytes on 1.4.1, expected ~57 KB; measured on the bench (§8 step 5).

### 4.2 Decode and verdict
- The decoder accepts sector ids `0 .. nsec-1` where `nsec` is **the mounted disk's** sector count (11 for DD/MFM
  slots, 22 for `SLOT_KIND_ADF_HD`), never inferred from the data. `found` becomes `uint32_t`; the decoded buffer holds
  22 sectors.
- A track is complete when all `nsec` sectors decode with good checksums (`(1u << nsec) - 1`). The existing verdict
  order (token checks, overflow, partial, inconsistent, wrong track) is unchanged; reason strings name the count.
- A DD disk never accepts a 22-sector track; an HD disk never accepts an 11-sector one.

### 4.3 Store
- HD: the verified 11,264 bytes are written straight into the track's `ADF_HD` slot (a new store path that allows
  ADF_HD); the track cache is invalidated so the next read re-encodes it (already how HD is served).
- DD: unchanged (MFM re-encode into the MFM slot).

### 4.4 Upload
- HD: the uploader reads the stored 11,264 bytes directly (`psram_image_track_data`), no re-decode, and posts them.
- The session-close sha-256 covers 160 tracks at the disk's track size (5,632 or 11,264).
- Protocol, sequencing, offline catch-up: unchanged.

### 4.5 Write protection
- `write_back_wprot` stops forcing HD; WPROT follows the server's `writeProtected` (plus the existing `!mounted` and
  uploader-forced terms). The read-only-only code (`WB_REJECT_READ_ONLY`, the `read_only_image` term) is removed.

### 4.6 Version
Firmware **1.5.0**.

## 5. Server: write-back and history

### 5.1 Uploads
- `stageTrack` looks up the disk first and requires a body of **5,632 bytes for DD, 11,264 for HD**; any other size,
  or the wrong one for the disk's type, is `400 invalid_body`.
- `closeSession` overlays tracks at the disk's track size and records a new version (unchanged flow).

### 5.2 History
- `src/lib/disk-history` takes the sector count from the image (1,760 or 3,520). The WDLD delta format is unchanged.
  Every "is this a whole image" check accepts either size, but a version must be the same size as its disk's current
  image (mixing sizes within one disk is refused).
- Restore, browsing old versions and the "what changed" column work for HD (file level via §6).

### 5.3 Read-only removed
Removed: `readDesired`'s forced `writeProtected` for HD; the locked write-protect toggle (disk row) and the drive chips'
Protect `readOnly: 'HD'`; the HD refusals in `device-write.ts`, `disk-write.ts`, `restore.ts`, `volume-name`,
`files/batch`, `files/[block]`, and the write-protect PATCH; the "HD disks can't be browsed in the browser yet"
message and `hd_not_browsable` / `hd_read_only` where they only served read-only. `plays_hd` and the
`hd_unsupported` mount gate stay (they are about playing HD at all).

### 5.4 Older boards
A board on 1.4.1 still forces HD read-only in firmware; an HD disk set writable is still protected on such a board until
it updates. Documented in HANDOFF; no capability flag.

No database migration.

## 6. Filesystem (`src/lib/adffs`), browser editing, blank HD disks

### 6.1 Geometry
- A geometry value `{ blockCount, rootBlock }` is derived from the image length: 901,120 → 1,760/880; 1,802,240 →
  3,520/1,760; anything else stays `not-adf`. Every read/write/allocate/format path takes it instead of the constants.
- No new structures: one bitmap block covers 3,518 bits (capacity 4,064); directory hash tables, file header and data
  blocks are the same size.

### 6.2 Browser editing
All file operations (add, rename, move, delete, folder drop, drag and drop), the free-space bar and the volume name work
for HD; every edit is a new version with file-level "what changed".

### 6.3 Blank HD disks
The create control gets a DD/HD choice beside OFS/FFS (default DD); `/api/disks/create` takes the size and formats a
1.76 MB disk with the chosen filesystem.

### 6.4 Independent check
HD images are checked with `xdftool` in both directions (as `pnpm adffs:verify` does for DD): our blank HD disks open in
xdftool; files we add list and extract there; an xdftool-made HD disk reads correctly in our code.

## 7. Tests

- **vitest, adffs:** the DD suite also runs on HD geometry; format/add/rename/move/delete/allocate cross-checked with
  xdftool both ways.
- **vitest, history:** HD versions record, restore and produce file-level diffs; mixed sizes refused.
- **vitest, write route:** HD tracks are 11,264 bytes; wrong size for the disk's type refused; closing a session yields
  the correct HD image.
- **Firmware host:** an HD track encoded by Greaseweazle (independent) goes through decode → verdict → store →
  uploader read-back and must equal the ADF bytes; an 800 ms capture fits the buffer; a DD disk rejects a 22-sector
  track and an HD disk an 11-sector one.
- **e2e (PORT=3100, full suite before merge):** create a blank HD disk, add and rename a file, see the versions; a
  simulated board's full HD write session; restore an older HD version.

## 8. Bench (A5000 rev 8a.1, Kickstart 3.1)

1. DD regression: a DD disk boots and a DD save still reaches the library.
2. HD save: HD Workbench disk set writable in the web app; `Echo >DF0:hello hi` and `Copy RAM:HDCheck.txt DF0:copy.txt`;
   the new version appears with both files and can be browsed.
3. Large write: a several-hundred-KB copy onto the HD disk; every track verifies and the library's version matches.
4. Offline: save to HD with WiFi down; the version arrives when WiFi returns.
5. Memory: the heap low-water during an HD write stays comfortably above what TLS needs.
6. Restore: an old HD version put back; the Amiga sees it after the disk change.

## 9. Rollout

The web app ships first (1.4.1 boards still protect HD themselves). Firmware 1.5.0 is published to the registry only
after bench steps 1 and 2 pass on it. README and HANDOFF updated.

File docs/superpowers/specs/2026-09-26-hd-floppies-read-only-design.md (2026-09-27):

# HD floppies, read-only — design

Status: approved in conversation 2026-09-26, section by section. Written spec awaits operator review.

## 1. What this is for

The operator wants 1.76 MB HD Amiga disks in the library and playing on a real Amiga through
the board, on a par with the 880 KB DD disks. This first release is **read-only on the Amiga:
boot and load**. Saves, browser editing of HD disks, and blank HD disks come later.

Done means: an HD ADF uploaded to the library boots and loads on the bench Amiga through the
board; DD disks, HFE and DF1 behave exactly as before; swapping between DD and HD works (with
a reset if Kickstart requires one, see §5.4).

## 2. Decisions taken

| Decision | By, when |
|---|---|
| HD is held on the device as ADF and encoded to MFM on demand, per track | operator ruling 2026-09-13, re-confirmed 2026-09-26 (approach A) |
| v1 is read-only on the Amiga: boot and load; saves later | operator, 2026-09-26 |
| v1 has no browser file editing, no history and no blank-disk creation for HD | operator took the recommendation, 2026-09-26 |
| Kickstart 3.0+ is required for HD; older Kickstarts are documented, not worked around | operator ruling 2026-09-13 |
| Out of scope: HD in `.dms`, HD HFE, Amiga writes to HD disks | this design |

## 3. What the spike measured (2026-09-26, HANDOFF backlog "HD floppies -- SPIKE DONE")

- One HD track (22 sectors, 202,688 bits, 25,336 bytes of MFM) encodes on the RP2350 in a
  median 3.7 ms from SRAM, 4.1 ms reading the ADF from PSRAM, worst seen 4.9 ms. The head
  settle budget is ~15 ms.
- `adf_mfm.c` (branch `spike/hd-floppy`) is byte-identical to `src/lib/adfmfm` on 5 real DD
  disks x 160 tracks and to Greaseweazle's HD encoding.
- A PIO state machine answering one ID bit on RDY per motor-off SEL0 select works at bus
  speed. The DD build answered 32 selects and booted Workbench 3.1.
- **Its phase was one select early.** Logical `0xAAAAAAAA` on the wire gave a black screen
  (invalid ID, DF0 never accessed); `0x55555555` on the wire made Kickstart 3.1 treat DF0 as
  HD ("read error on block 56" on a DD disk, as expected). Kickstart read the ID again later
  while running (a second burst of 49 motor-off selects after track reads).
- Firmware RAM today: 342 KB of 512 KB used by static data, ~170 KB free.

## 4. Library and server

### 4.1 Recognising HD
- An ADF (`imageFormat = 'adf'`) of exactly 1,802,240 bytes is HD; 901,120 bytes is DD. No
  schema change for disks: one helper, `adfDensity(sizeBytes): 'dd' | 'hd' | null`, in
  `src/lib/disk-format.ts`, is the only place that knows the two sizes' meaning.
- Ingest already accepts HD ADFs and `.adz` (size cap 2.5 MiB). `.dms` keeps its DD-only
  rejection.
- TOSEC identification matches on crc32 + size and needs no change.

### 4.2 In the library
- HD disks show an "HD" tag beside their size wherever size is shown (`disk-row.tsx`,
  `game-table.tsx`, the dropzone result).
- The disk page's file browser says "HD disks can't be browsed in the browser yet" instead
  of today's "not a standard 880 KB ADF". The file, volume-name, history and edit routes
  keep refusing HD disks; they must refuse with that reason, not crash or mislabel.

### 4.3 Mounting
- `isServable` accepts HD ADFs.
- The board reports the capability in its status: `playsHd: true` (absent means false).
  Stored as a new `devices.playsHd boolean not null default false` column, set from each
  status report.
- `setDesired` refuses an HD disk on a device whose `playsHd` is false with a new reason,
  `hd_unsupported`, alongside the existing `track_too_long`. Every mount entry point (web
  mount, drive chips, NFC tap) surfaces it as "Update the drive's firmware to play HD disks".
  An NFC tap of an HD disk on such a board is refused the same way, not silently dropped.
- `readDesired` always sends an HD disk with `writeProtected: true`, whatever the disk's
  library setting. The write-protect toggle is disabled for HD disks in the UI.
- The write routes (`device-write.ts`, `disk-write.ts`) refuse writes to HD disks, as they do
  for HFE (`409`, reason `hd_read_only`).

### 4.4 What the board downloads
`GET /api/device/image/[sha256]` keeps sending WFMF for DD and HFE, unchanged. For an HD disk
it sends a **WFAD** container, all integers little-endian like WFMF:

| offset | bytes | field |
|---|---|---|
| 0 | 4 | magic `WFAD` (a new constant beside `WFMF_MAGIC`) |
| 4 | 4 | version = 1 |
| 8 | 4 | tracks = 160 |
| 12 | 4 | sectors per track = 22 |
| 16 | 1,802,240 | the ADF, track-major (track = cylinder x 2 + head), 22 x 512 bytes each |

Total 1,802,256 bytes. The writer lives in `src/lib/adfmfm/wfad.ts` and throws on any other
input size.

## 5. Firmware

### 5.1 Loading
- `image_loader.c` dispatches on the magic. WFMF takes today's path unchanged.
- WFAD is validated before anything is published: version 1, 160 tracks, 22 sectors, body
  exactly 1,802,240 bytes. Any failure rejects the whole image, as an oversized WFMF track
  does today; a partly loaded disk is never mounted.
- Each track's 11,264 bytes go into that track's existing PSRAM slot (14,336 bytes per
  track, unchanged). The slot records its kind: `MFM` (ready to play) or `ADF_HD` (encode on
  read). `device_image`, the slot count and the 2 MiB firmware stage do not change.

### 5.2 Serving a track
- `track_cache_get` on a miss copies from PSRAM today. For an `ADF_HD` slot it instead
  encodes the track's sector data with `adf_mfm.c` straight into the idle SRAM buffer and sets
  `bit_count = 202,688`. The token-tagged double buffer and its stale-track guarantee apply
  unchanged.
- Streaming is unchanged: the revolution follows `bit_count`, so an HD revolution is 400 ms
  at the same 2 us cell and INDEX fires at the wrap.
- The SRAM buffers (`track_cache.c` `buf[2]`, `main.c` `track_words`) are sized by a new
  `TRACK_BUF_BYTES = 25,344` (25,336 rounded up to 4), separate from the PSRAM stride
  `TRACK_MAX_BYTES`. Cost ~33 KB, leaving ~140 KB free.
- The plan must establish where `track_cache_get` runs. The 4-5 ms encode must not run in an
  interrupt handler; if the call site is one, the encode moves to the point where the next
  buffer is prepared.

### 5.3 Read-only
- With an `ADF_HD` disk mounted the board drives WPROT asserted, independent of the server's
  `writeProtected` (joins the `wprot = ...` expression in `main.c`).
- A write captured while an HD disk is mounted is discarded and never uploaded.

### 5.4 Drive ID
**Updated 2026-09-27 (firmware 1.4.1; supersedes the Phase bullet and the clkdiv below):** the phase is
the amiga-hddlw PAL's (github.com/schlae/amiga-hddlw, pal/amiga-hddlw.pld): a motor-ON select resets
the answer, and the FIRST motor-off select after it carries bit 31, asserted = 1 = GPIO high (/RDY low);
the Amiga samples 32 motor-off selects from that one and reads `0xAAAAAAAA` (HD) / `0xFFFFFFFF` (DD).
1.4.0's HD answer never reached the wire because pico-sdk 2.3.0's `pio_encode_mov(pio_osr, src)`
encodes `mov pindirs, src` in release builds, switching RDY's output off on every HD reload; the load
words are now built from the MOV fields (`drive_id_load`, HD `0xa0e2` `mov osr, y`, DD `0xa0eb`
`mov osr, ~null`). The HD word lives in Y (seeded at init), MTR is tested with `jmp pin` (jmp_pin =
MTR), and the program runs at clkdiv 10 so MTR has ~0.5 us to settle after SEL0 falls. HANDOFF §3an.

- The spike's PIO `drive_id` program (pio0, clkdiv 1) becomes permanent, gated on SEL0 only,
  so a real drive on DF1 is untouched.
- **Phase:** the select that resets the ID (first motor-off select after the motor was on)
  carries no bit; bit 31 goes out on the next motor-off select. The reference is a host test
  in `test/test_drive_id.c` that plays the Amiga's sequence (motor on, motor off, 32
  selects) through the pure model in `drive_id.c` and asserts the Amiga reads `0xAAAAAAAA`
  for HD and `0xFFFFFFFF` for DD, sampling RDY active-low. The PIO program is changed to match
  the model. The bench workaround word `0x55555555` is not used.
- **What it answers:** `ADF_HD` disk mounted: HD `0xAAAAAAAA`. DD, HFE or no disk: DD
  `0xFFFFFFFF`. The main loop pushes the new word when the mounted kind changes; the PIO takes
  it at the next reset select, never mid-answer.
- **Swapping without a reboot:** whether Kickstart 3.x re-reads the ID on a disk change is
  tested on the bench (§7, step 9). If it does not, the fallback is documented, not
  engineered: the web app notes "reset the Amiga (Ctrl-Amiga-Amiga) after switching between
  DD and HD" when a disk of the other density is mounted.
- **Kill switch:** build option `WF_DRIVE_ID=OFF` removes the responder. With it off the board
  reports `playsHd: false`, so the server refuses HD mounts cleanly.

### 5.5 Status
The status report adds `playsHd: true` when the drive-ID responder is built in.

## 6. Failure handling

| Case | Result |
|---|---|
| HD mount on a board without `playsHd` | refused, "Update the drive's firmware to play HD disks" |
| WFAD truncated, wrong version, wrong size | whole image rejected, nothing published, logged |
| Amiga writes to an HD disk | Amiga shows "Disk is write protected"; any captured write discarded |
| Server asked to write an HD disk | `409 hd_read_only` |
| HD disk opened in the file browser | "HD disks can't be browsed in the browser yet" |
| Kickstart < 3.0 | HD disk does not read; documented |

## 7. Tests

**Web (vitest):** `adfDensity`; `isServable` for HD; `setDesired` returns `hd_unsupported`
for a device without `playsHd` and succeeds with it; `readDesired` forces `writeProtected`
for HD; write routes return `hd_read_only`; the WFAD writer byte for byte against a golden
file, and rejects wrong sizes.

**Web (e2e, port 3100, full suite green before merge):** upload an HD ADF and see the HD tag
and the disk-page message; mount it on a simulated device that reports `playsHd` (accepted)
and one that does not (refused with the message).

**Firmware (host):** WFAD loader accepts valid and rejects truncated, wrong-version and
wrong-size containers; an end-to-end host test runs WFAD -> loader -> `track_cache_get` for
all 160 tracks and compares each against **Greaseweazle's** HD encoding of the same ADF
(independent verifier); the stale-track guarantee on HD slots; the drive-ID phase test;
WPROT forced for `ADF_HD`.

**Test disk:** a bootable HD ADF built with `xdftool` (1.76 MB, FFS), the Workbench 3.1 files
copied onto it and a boot block installed, plus one known file whose checksum is recorded.
Also look for real HD ADFs from TOSEC in the library to try one not built here.

**Bench checklist (each step a visible pass/fail):**
1. DD Workbench 3.1 boots (regression)
2. A DD game loads (regression)
3. Turrican (HFE) boots (regression)
4. DF1 with the real drive works (regression)
5. NFC tap mounts a DD disk (regression)
6. The HD Workbench disk boots
7. Its Workbench window shows ~1.7 MB capacity; the known file copies to RAM: and its checksum matches
8. Saving to the HD disk gives "Disk is write protected"
9. Swap DD -> HD and HD -> DD while running; record whether a reset is needed (§5.4)
10. The serial log's low-water mark of free heap confirms the RAM headroom

## 8. Rollout
- The web app ships first. It refuses HD mounts until a board reports `playsHd`, so the order
  is safe.
- Firmware 1.4.0 goes out through the release registry and updates from the web app.
- `README.md` and the end-user feature list gain HD (read-only, Kickstart 3.0+).

## 9. Out of scope (next steps, in order)
1. Browser editing, history and blank HD disks (`adffs` geometry parameterised; root block
   1760, 3,520 blocks, one bitmap block still suffices).
2. Amiga writes to HD disks (write-back decode for 22 sectors).
3. HD in `.dms` and HD HFE.

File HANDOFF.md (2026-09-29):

# webadf — session handoff

**Written 2026-08-29, updated 2026-08-30 after plan 3b, updated again 2026-08-30 after
plan 4a, updated again 2026-08-31 after plan 4b.** Everything a fresh session needs to pick
this up cold. Read this first, then the spec, then the plan you are resuming.

---

## What this project is

A web app that stores an Amiga floppy-disk library and mounts disks to real Amiga
hardware over WiFi. You upload ADFs; each unique disk is stored once, keyed by its
SHA-256; you browse them and press mount; a custom board emulates the floppy drive.

**Live:** https://webadf.vercel.app · **Repo:** `stefanskotte/webadf` (private)

---

## Where things stand

**Written 2026-08-29; table re-checked row by row against git and the board on 2026-09-25.**

| | Status |
|---|---|
| **Plan 1 — foundation & library** | ✅ merged to `master`, in production |
| **Plan 2 — device plane** | ✅ tasks 1–4 done; **6–8 superseded** by plan 3a, not pending |
| **MFM encoder (`adfmfm`)** | ✅ **done** — byte-identical to Greaseweazle across all 61 archive disks (9,760 tracks) |
| **Plan 3a — device protocol** | ✅ done, merged to `master`, pushed |
| **Plan 3b — device UI** | ✅ **done, all 7 tasks, merged to `master`** |
| **Plan 4a — firmware protocol plane** | ✅ **done, merged to `master`, pushed.** Firmware compiles and has a green host suite. |
| **Plan 4b — captive portal** | ✅ **done, all 8 tasks.** Compile-time WiFi/pairing-code defines are gone, replaced by an AP-mode portal. Merged to `master` and pushed. |
| **Plan 5 — hardware bring-up** | ✅ **done on rev A2.** Portal, TLS, pairing, mount/eject, OLED, LED; the Amiga reads (WB3.1 boots), writes, and a second drive (DF1) works via SEL0 gating; see 3x, 3y, 4b–4e |
| **Super-admin plane** | ✅ **done, all 6 tasks, merged to `master` and live in production.** `/admin`: overview, user list with cascade delete, invites |
| **TOSEC identity scan** | ✅ **done, 12 tasks, merged to `master`.** `/admin/scan`: DAT import, hashing, matching, backfill |
| **OpenRetro enrichment** | ✅ **done, all 9 tasks, merged to `master` and live in production.** Enriches 6.6% of the real archive against TOSEC's 45.9%; see 3d |
| **e2e cleanup** | ✅ **done, merged and live 2026-09-01.** A run no longer leaks; 4,600 accumulated rows and 73 live invite codes swept; see 3e |
| **User-defined collections** | ✅ **done, all 9 tasks, merged to `master` and live in production.** A rail on `/library`, drag to file and to reorder; migration 0011 applied; see 3g |
| **Library covers, type pills, contrast** | ✅ **done, merged and live 2026-09-01.** Grid shows real cover art; grid and table both show a TOSEC-derived type; the grey ramp now passes WCAG AA |
| **Firmware updates (OTA) — CLOSED** | ✅ **done and closed 2026-09-25.** Registry (3ai), server half 2a (3aj, merged 2026-09-22) and board half 2b (3ak, merged 2026-09-23): select boards, press Update, confirm with the password, the board downloads a signed image into its other slot and confirms on boot. Used for real to ship 1.1.4 (seq 8) and 1.2.0 (seq 9). **Operator ruling 2026-09-25: the password-to-update flow is the finished feature** — no auto-update opt-in, no further increment |
| **Firmware release registry** | ✅ **done 2026-09-22.** The version identifies a build and is refreshed on every heartbeat; `firmware_releases` + `/admin/firmware`; Devices says which boards are behind; see 3ai |
| **Shell polish** | ✅ **done 2026-09-02.** The "/" hint, both navs centred on the viewport, zebra-striped file tree, and a navigation bar + scrim; see 3i |
| **Mobile responsive** | ✅ **done 2026-09-02, all surfaces.** Usable at 390px; nav becomes a bottom bar, touch drag no longer eats scrolling; see 3j |
| **Delete a title or a disk** | ✅ **done 2026-09-04.** Confirmation dialog, deliberate eject, blob never destroyed; see 3o |
| **Disk space on the browse page** | ✅ **done 2026-09-04.** Read from the allocation bitmap, agreeing with xdftool on 46 of 46 real disks; see 3p |
| **Create a blank ADF** | ✅ **done 2026-09-03.** A real formatted disk from a button, named inline; migration 0013 applied; see 3n. File add/edit/delete is NOT part of it |
| **Create ADF is one menu** | ✅ **done 2026-09-04.** One dropdown with FFS and OFS items replaces the sticky select plus button; the filesystem is no longer remembered between disks; see 3t |
| **Files inside an ADF** | ✅ **done 2026-09-04.** Add, delete, rename, replace contents, make and remove directories, through the browse page; every operation checked against xdftool rather than against our own reader; see 3u |
| **Drop a folder in, drag to rearrange** | ✅ **done 2026-09-05.** Drop from the OS into a staging area that checks fit in BLOCKS before writing; one commit, one blob; drag or keyboard to move entries between folders; see 3v |
| **Deleting the last disk no longer 404s** | ✅ **done 2026-09-05.** Navigates on the server's own `gameDeleted`, replaces rather than pushes, and goes where the breadcrumb points; see 3w |
| **Drag and drop inside an ADF** | ✅ **done 2026-09-05, all 11 tasks, merged to `master` and live.** Drop a folder from the OS to stage and batch-commit it as one blob; drag or keyboard-move an entry between directories; a cycle refusal our own reader cannot see the need for; see 3v |
| **Edit a title by hand** | ✅ **done 2026-09-03.** Per-group authority, and a scan never silently undoes an edit; see 3m |
| **Unified breadcrumb** | ✅ **done 2026-09-03**, and 2026-09-04 it follows the collection you came from; see 3l and 3r |
| **Image layout shift** | ✅ **done 2026-09-03.** The game page's cover and screenshots reserve their space; the library grid never had the bug; see 3k |
| **Typeahead search** | ✅ **done, all 7 tasks, merged to `master` and live in production.** A Spotlight-style pill in both shells; migration 0012 applied; see 3h |
| **Read-only ADF filesystem reader** | ✅ **done, all 10 tasks, merged to `master` (`src/lib/adffs`).** Reads 80.3% of the archive (49/61) against TOSEC's 45.9% and OpenRetro's 6.6%; see 3f |
| **Demozoo identification** | ✅ **done 2026-09-14, all 16 tasks, merged to `master`.** Complements TOSEC for non-games: weekly import, nightly matching, automatic links, suggestions, review queue, screenshots; see 3af |
| **Write-back piece 3 — the time machine** | ✅ **done 2026-09-21, merged to `master`.** History panel on every disk page: what changed per version, Browse read-only, Restore as a new version. **Restore passed on hardware 2026-09-22** (DB-confirmed rewind of v10 as v12); see 4l |
| **Write-back piece 2b (board)** | ✅ **done 2026-09-19, verified on hardware.** Amiga saves upload, close and land on the server as history versions, including offline and eject-right-after; keep-alive connection (4k). Two paths never yet run on the board: a multi-file save burst over keep-alive, and `up_forces_wprot`; see 4i–4k |
| **Write-back piece 2a (server)** | ✅ **done 2026-09-18, 5 tasks + final fix wave, merged to `master`.** Disk history tables, browser edits and renames recorded as versions, `POST /api/device/write` + `/close`, live write-protect; see 4g |
| **HFE v1 disks** | ✅ **done 2026-09-24, merged and live; bench-proven 2026-09-25.** Upload keeps the `.hfe`, the board plays it read-only, "Extract as ADF" when every sector decodes. Long-track HFEs (fw 1.2.0, 14 KB tracks, per-board `trackMaxBytes`): **Turrican boots on the Amiga**; extract round trip passed byte-exact. Only the weak-bit bench item is owed (needs a weak-bit HFE). A cylinder-17 hang after a disk swap is parked; see 3al, 3al-a |
| **NFC tap-to-mount** | ✅ **merged and live 2026-09-26 (master 0f6fbd1); firmware 1.3.0 (seq 10) confirmed on the board.** Tap a tag → the board mounts that disk from its own org's library (swap; same tag = no-op; 1 s rate limit). Claude writes tags: `pnpm nfc:write "<disk>"` arms the board through the poll, you tap a blank tag, the read-back is reported. HW-147C/Si512 reader on I2C1 (0x28). **Firmware 1.3.1 (seq 11, 2026-09-26): a tap needs 3 s of absence; a write never lands on a tag already on the reader.** Bench: write + tap-mount + same-tag proven; see §3am. **Fob button (2026-09-26, b6c4e7c):** an NFC icon on every library card and disk row writes that disk to a tag from the web (dialog picks disk and board, 2:00 countdown, read-back shown; withdraws on close/cancel/leave); shown only when a board reports a reader |
| **HD floppies, read-only** | ✅ **merged; firmware 1.4.1 verified on hardware 2026-09-27** (A5000, Kickstart 3.1); see 3an |
| **HD disks: writes, history, editing, blank disks** | ✅ **merged 2026-09-28; firmware 1.5.1 (seq 31) on the board.** Bench steps 4-7 and the rev B `short 0` retest owed; see 3ao |
| **Multi-disk "Next disk" + Next-disk NFC card + preload** | ✅ **bench-proven 2026-09-29 (all 3ap steps).** ⚠️→✅ **Step 4 lost a file header on Locale (block 597): the swap did not wait for the Amiga to finish writing. Fixed in firmware 1.6.1 (swap waits for the drive light), bench-proven 2026-09-29; see 3ar. Open: a restore under a running Amiga (3ar).** 🟡→✅ **merged 2026-09-28 (`92ec133`), web live; firmware 1.6.0 (seq 32) published and targeted, installs when the Amiga is on and idle.** Bench acceptance owed; see 3ap |
| **Disk sets** | ✅ **merged 2026-09-29 (`aa3520d`), live; migration 0028 applied.** A title with several disks, arranged by a person: upload suggestion, title-page Disk set section (add, reorder, move out, undo). See 3aq |
| **Drive chips in the header** | ✅ **done 2026-09-25, merged and live.** Every paired board as a chip beside the wordmark: status dot, name, mounted disk; caret menu with Go to disk (the game page), Disk is Protected/Writable, and Eject (no confirm, below a divider). Pending states while a mount or eject converges. 1 chip + "+k" at 1280, 2 at 1536, 3 at 1920; below 1280 a single "Drives" list. Fed by `liveStateRows` (now carries the mounted game/title/disk no/format, all in `liveFingerprint`); `src/lib/drive-chips.ts`, `src/components/shell/drive-chips.tsx`. Unverified: 640–700 px the Drives button overlaps the pill (the search box already does, 640–767 px, on master). **2026-09-26 (`b40699c`): the chips are centred in the gap between the wordmark and the pill** (`src/components/shell/header-start.tsx` measures the pill's width; equal gaps at 1280/1536/1920, with and without Admin), and the "+k" chip shows one number at ≥1920 (a Tailwind breakpoint-order bug had shown "+2 +1") |
| **Five minors, 2026-09-25** | ✅ **merged and live.** Update confirm is a real modal (role=dialog, Escape, focus, Enter submits); the 50-board cap (`MAX_UPDATE_BATCH`) shows in the update bar; re-extracting an EDITED extract is a 409 `already_extracted` with a link; the not-extractable reason is visible text; a refused HFE's bytes are deleted when nothing references them (a two-round-trip race is documented in `releaseRefused`) |
| **Hardware** | rev A scrap (mirrored), **rev A2 in hand and working**. **Rev B is Shanshe's KiCad project, merged 2026-09-26 (PR #1, `22d3556`) and now the primary PCB** -- the generated-board toolchain (`generate_pcb.py`, `verify_board.py`, `export_gerbers.py`, renders) is gone. `pnpm hw:verify` (`wifi-floppy/hardware/hw_verify.py`) runs KiCad ERC/DRC + parity and checks the netlist against the firmware and §4c. **PR #2 (2026-09-26, `d871430`): `hw:verify` PASSES** -- 1k pull-ups to +5V on all eight host-driven lines (WGATE, WDATA, MTR, DIR, STEP, SIDE, SEL0, SEL1), power flags fixed, J2 moved 0.1 mm to clear U1's RF keepout (keepout zones verified unchanged; J2 now sits right at its edge); the assembly BOM (DNP flags, LCSC numbers) is for the operator to complete when sourcing; GP20 (NFC reset) is not wired. See the rev B entry in §4 |

**Current branch (2026-09-25):** `master`, clean and pushed; everything in the table is merged
and live. The board runs firmware `1.2.0+ge8ac726` (seq 9). **No increment is in flight.**

**Owed at the bench:** NFC tap-to-mount acceptance (§3am). **Still open, none started:** the HFE weak-bit bench item; the two hardware-untested write-back
paths (2b row); the super-admin audit log; the rev B respin (with Shanshe); NFC (designed later,
tag writing is a Claude-driven USB tool). **Suite on master 2026-09-25: 1,101 vitest, build clean,
362/362 Playwright (1.1 h), run alone on the database.**

*Historical (2026-09-03 onward), kept for the record:* the write-protect flip on a mounted disk
was built in 4j. The suite counts below are from 2026-09-14; the full suite is now **349
Playwright tests, ~1.1 h** (2026-09-24) — run it on port 3100 with a dev server you start
yourself, logged to a file.
**Suite on `master`:** 821 vitest (1 skipped), `pnpm build` clean, **256 Playwright** — 247 desktop at
1280×720 and 9 mobile at 390×844 (measured 2026-09-14 before the Demozoo merge: a full run
passed 250; the 6 failures were a missing `adf-archive/` in the worktree and two TOSEC tests
whose real-demo fixture Demozoo now links, fixed with Games set names, and those three spec
files then passed 16/16). `playwright.config.ts` has two projects. **A git worktree has no
`adf-archive/`** (it is gitignored): symlink the main checkout's before running e2e there.

**Known flake shape, so nobody debugs it twice:** the first two or three tests of a cold run can
time out at the 30s per-test limit while Turbopack compiles a route for the first time —
observed as `apiRequestContext.post: Test timeout` on `/api/ingest/complete`, and as
`signUpFresh` never reaching `/library`. Both pass in isolation and on a warm re-run. Before
concluding a regression, **re-run the failing spec alone**; if it passes, that was this.

**A third, and it cost two hours on 2026-09-03: a killed run ORPHANS its dev server.**
`playwright.config.ts` sets `reuseExistingServer: true`, so the next run adopts whatever is
holding port 3000 -- including a wedged process that never answers HTTP. The run then waits
forever with **no output at all**, which reads exactly like a slow cold compile. The tell is
`ps -o etime,time`: hours of elapsed against under a second of CPU, and no
`chrome-headless-shell` process ever started. **After killing a run, kill `next dev` and
`next-server` too**, and check `lsof -iTCP:3000` is free before restarting.

**Its sibling: do not start a spec while the previous run's teardown is still going.**
`globalTeardown` sweeps every test user by email domain, and it keeps running after the last
test reports. A spec launched into that window has its freshly signed-up user deleted
underneath it, which shows up as several tests in one file failing in ~500ms each — a cascade
that looks alarming and is nothing. Observed 2026-09-03. Wait for the teardown line
(`teardown: removed N test users...`) before re-running anything. Firmware: `pnpm firmware:test` green (2,467 checks, 13
binaries), `pnpm firmware:build` produces a `.uf2` — **and now requires
`PORTAL_AP_PASSWORD` set in the environment, or the configure step fails by design**; see
"Plan 4b" below for the full command.

*(2026-08-31 text, superseded: plans 4a and 4b have since run end to end on a real board —
see the table above.)*

### Before you touch the device UI

The rulings taken during 3b are in `docs/decisions/2026-08-30-device-ui-rulings.md`. Read it
before touching the mount action or the queries — it records why the multi-device picker is an
inline expansion rather than the dropdown the spec originally specified, and that is the
decision most likely to look arbitrary later. Both points are also summarised under "What to
do next" below, because both have been rediscovered the hard way once already.

### What 3a and 3b built

Desired-state reconciliation, not a job queue. `devices` carries what a human asked for and
what the device reported, separately and on purpose. Three device endpoints —
`GET /api/device/poll` (25 s long-poll), `GET /api/device/image/<sha256>` (WFMF, encoded on
demand), `POST /api/device/status` — plus human-facing mount, eject and write-protect. Two
pages that previously 404'd, `/devices` and `/games/[id]`, now exist.

## The thing that changed mid-flight — read this before anything else

The target hardware was redesigned during plan 2. It is no longer an ESP32 dongle
presenting USB mass storage to a Gotek. It is now a **self-designed RP2350 board**
(Pimoroni Pico Plus 2 W core) in `wifi-floppy/` that **emulates the floppy bus
directly** with PIO. There is no Gotek in the path at all.

Recorded as spec decisions **D14, D15, D16** (commit `2d81dd8`). **D5 is superseded**;
D10's *mechanism* is superseded but its "one disk at a time" property still holds.

What that invalidated:

| Old assumption | Reality |
|---|---|
| Serves raw ADF (901,120 B) | Serves **pre-encoded Amiga MFM**, ~2 MB, `WFMF` container |
| Device fetches a presigned Vercel Blob URL | Device fetches `GET /api/device/image/<sha256>` **from webadf** |
| Server does no encoding | Server **must implement an Amiga MFM encoder** |
| Long-poll returns a blob URL | Poll returns the image *identity*; the image is a separate fetch |

The format is defined by `wifi-floppy/firmware/src/image_loader.c` and documented in
`INTEGRATION.md`. The firmware and hardware trees were moved into this repo precisely
so the format and its encoder cannot drift apart.

---

## What to do next, in order

### 0. Two invariants in the 3b code that look like cruft and are not

Not a task — a warning, first because both are one refactor away from being undone:

- The multi-device picker is an **inline expansion, not a dropdown**, though spec §4
  originally said dropdown. A dropdown was built and measured to have a wrong-target bug —
  the open popup covered the next row's Mount button, so clicking what looked like disk 2's
  Mount silently mounted disk 1. `modal={true}` does not fix it (`MenuPositioner`'s `z-50`
  is unconditional) and neither does any placement. Do not "restore" the dropdown.
- `listDevices`'s org-scoped join on `games` is **preventing a live cross-tenant leak**.
  The production database holds three devices whose `desired_game_id` belongs to another
  organization — leftover e2e data, and that column has no foreign key. Removing the
  predicate puts a foreign title on the page. There is a test for it; do not weaken it.

### 1. Plan 4a — done. Read this before touching firmware.

Plan 4a shipped (merged to `master`):
mbedTLS with a provisioned bearer token per D16, the full §10 device-contract state
machine, two-slot PSRAM with fetch-before-transition, and both recorded firmware defects
fixed (`TRACK_SLOT_BYTES`/`TRACK_MFM_MAX` collapsed into one `TRACK_MAX_BYTES`; `bits` now
bounded before the `(bits + 7) / 8` arithmetic in `image_loader.c`). `http_fetch.c`/`.h`
— the old plaintext, path-addressed, credential-less fetcher — are deleted.

Full detail, including what got deferred and the rulings taken along the way, is in
`docs/superpowers/specs/2026-08-30-device-firmware-protocol-design.md`'s "What plan 4a
delivered" section and in "Before you touch the firmware again" below.

**Build and test commands (see also "Commands" at the bottom):**

```bash
# Both of these, copy-pasteable, from the repo root. The two exports are
# required for the BUILD, not the tests: plan 4b made PORTAL_AP_PASSWORD a
# hard CMake FATAL_ERROR (an empty WPA2 PSK cannot be reported back to a
# console-less board at runtime, so it is refused at configure time), and
# homebrew's arm-none-eabi-gcc ships no newlib and will not link.
export PATH="/Applications/ArmGNUToolchain/15.3.rel1/arm-none-eabi/bin:$PATH"
export PORTAL_AP_PASSWORD=<any WPA2 PSK, 8-63 chars>
pnpm firmware:build   # also needs pico-sdk >= 2.3.0 checked out (PICO_SDK_PATH).
                      # If configure behaves oddly, rm -rf wifi-floppy/firmware/build.
pnpm firmware:test    # plain C under clang, no toolchain/SDK/env vars needed --
                      # 506 checks across 13 binaries (measured, plan 4b final)
```

**`src/lib/adfmfm/firmware-parser.ts` no longer mirrors the bit-count-overflow defect** —
it was fixed in the same change as the firmware fix, and the mirror was updated with it.
Older guidance (in this file and in the design spec) said never to "fix" that mirror; that
instruction was correct only while the firmware was actually broken, and is now inverted.
Do not reintroduce the wrapped-`bits` behaviour into the mirror.

### 2. Plan 4b — done. Read this before touching provisioning.

Plan 4b replaced the compile-time `WIFI_SSID`/`WIFI_PASS`/`WEBADF_PAIRING_CODE` defines
with an AP-mode captive portal. **`WEBADF_HOST` stays compile-time, deliberately** — it
changes only if the deployment itself moves, and making it portal-editable would let anyone
who reaches the AP point a board at a server of their own choosing, which is a real attack
surface nobody needs.

**How it works:** a board with no stored credentials, or one that fails to associate three
times in a row, raises a WPA2 access point named `wifi-floppy-XXXX` (the board's last two
MAC octets). Joining it and opening any page serves a config form asking for SSID, password
and a webadf pairing code. Credentials are verified before anything is written to flash: the
AP drops, the board attempts association with what was typed, and only success triggers a
flash write — on failure the AP comes back with the reason, distinguishing a wrong password
from a network that was not found. Storage is `config_store`, a dedicated CRC-protected
flash sector below `token_store`'s; erasing it also erases the device token, since re-pairing
always issues a new one. A rejected pairing code, a revoked token, or a device deleted in the
web UI all now return the board to the portal rather than requiring a reflash — see
`docs/decisions/2026-08-31-device-portal-rulings.md`'s "Ruling 8" section for how that last
behaviour was added, and for a real fleet-wide regression it introduced and was then
corrected to avoid.

**The portal is not a one-way door.** If the board still has a usable configuration in flash
(it got there by failing to associate three times, not by a rejected pairing code), the AP
comes down after **five minutes with no client traffic at all** and the stored credentials
are re-tried; if those fail their three attempts again, the AP comes back, and so on. That
is what stops a power cut which drops the router and the board together — board boots first,
burns 45 s of attempts while the router is still starting — from parking a board in AP mode
until someone turns up with a phone. The window is inactivity, not a wall clock: any DHCP,
DNS or HTTP packet restarts it, and it is never even evaluated while an HTTP connection is
open, so nobody filling in the form is cut off. With nothing stored to re-try, the wait is
indefinite by design. Constant is `PORTAL_IDLE_TIMEOUT_MS` in `src/portal_net.h`.

**Two spec sections were corrected in place** (not just amended in the delivered-section
addendum) by the final pre-merge review: **§2**, because `main.c`'s `DC_HALTED` recovery
ejects a mounted disk before dropping to the portal, so the old absolute "a board that is
already serving a disk never drops into the portal" was false — §2 now states the rule as
"never *spontaneously*, with one deliberate ejecting exception" and names it; and **D-4b-1**,
for the bounded wait above. §2 is the invariant plan 5 will be read against, so read it
there, not here.

**New build prerequisite:** `PORTAL_AP_PASSWORD` (the provisioning AP's WPA2 PSK) must be
set in the environment, or CMake's configure step fails by design — an empty PSK cannot be
reported back to a console-less board at runtime, so it is refused at build time instead.
The full build incantation is now:

```bash
export PATH="/Applications/ArmGNUToolchain/15.3.rel1/arm-none-eabi/bin:$PATH"
export PORTAL_AP_PASSWORD=<your AP password>
pnpm firmware:build
```

Full detail — what shipped, what changed shape mid-plan, and what plan 5 still owes — is in
`docs/superpowers/specs/2026-08-30-device-provisioning-portal-design.md`'s "What plan 4b
delivered" section and in `docs/decisions/2026-08-31-device-portal-rulings.md`.

### 3. Plan 5 — hardware bring-up, the only piece left

Once boards arrive. **Nothing in plan 4a or plan 4b has run on real hardware** — no TLS
handshake, no SNTP sync, no floppy-bus timing, and none of the AP-mode portal's lwIP/cyw43
glue has ever been exercised outside the host suite and the cross-build. Treat every claim
about TLS, timing, the floppy bus, or the portal's radio behaviour as desk-checked and
host-tested only, not hardware-verified, until plan 5 says otherwise.

**SUPERSEDED 2026-09-10 -- READ 3y FIRST.** A rev A2 board has now provisioned itself,
registered with production and run the poll loop. Every bullet below except the floppy-bus
and Android ones is ANSWERED there, and answering them took three fixes (an lwIP timeout-
pool panic, an unparseable root CA bundle, and the logger's own two in 3x). The list is
kept as written because it is what the bullets were before the board ran, and because 3y's
answers only mean something against it. Specifically open, carried forward verbatim from
plan 4b's ledger:

- Whether `netif_default` is really restored to STA (not left NULL) after the provisioning
  AP tears down, and TLS to webadf actually succeeds afterward — the entire point of a
  Critical fix in plan 4b that has never been run.
- Whether the confirmation page physically leaves the radio before AP teardown.
- STA DHCP lease acquisition/renewal after the AP netif has been removed.
- Real phone captive-portal behaviour against the portal's 2-lease DHCP pool
  (`DHCP_POOL_SIZE`) and its 3 concurrent HTTP slots (`MAX_HTTP_CONNS`), including
  MAC-randomization retry storms and the ~30 s idle reclaim.
- Whether the iOS and Android captive-portal probe URLs actually trigger the sign-in sheet
  on real devices.

### 3b. Super-admin plane — DONE, all 6 tasks

**Branch `feat/super-admin`, complete and green: 256 vitest, 107 Playwright, `pnpm build`
clean.** Not merged to `master` yet. Rulings, deviations and mutation results are in
`docs/decisions/2026-08-31-super-admin-rulings.md`; the spec carries a "What this plan
delivered" section.

An operator-only plane at **`/admin`** — an overview of unscoped counts, a paginated user list
with a real cascade delete, and invite issue/revoke. Identity is an env-var email allowlist
(`SUPERADMIN_EMAILS`), deliberately outside the database so a database compromise cannot grant
it. There is an **Admin** entry in the app's top nav, rendered only for an allowlisted user.

**The bootstrap sequence, and it is security-relevant in this order:**

1. ~~The operator signs up and claims `sfs@enhance-it.dk`.~~ **DONE 2026-08-31** — the account
   exists (role `owner`), so the unique constraint on `user.email` protects that address
   permanently. This had to come first: `emailVerified` defaults to false and nothing enforces
   it, so an *unclaimed* allowlisted address is a prize.
2. ~~Revoke the invite codes that leaked into a session transcript.~~ **DONE 2026-08-31** —
   `M3W4V3BA` was consumed by step 1; `56DTUDMA`, `HXGMH4ZK` and `K69GXH72` were deleted.
3. ~~`vercel env add SUPERADMIN_EMAILS production` → `sfs@enhance-it.dk`, then redeploy.~~
   **DONE 2026-08-31.** The variable is set (Secret, Production only), the branch was merged
   fast-forward to `master`, and the push deployed to production —
   `webadf.vercel.app` → `webadf-eo0n3qmtc`, `target: production`. **The operator has confirmed
   `/admin` works for `sfs@enhance-it.dk` in production.** An unset variable would have denied
   everyone rather than allowing them, so this always failed closed.

`.env.local` needs `SUPERADMIN_EMAILS=admin@example.test` for local dev and e2e — a *different*
value from production, deliberately (Ruling 1). A single shared value would either put a test
account in production's allowlist or leave the e2e unable to sign in as an admin.

**Two things worth knowing before you touch it:**

- **`src/lib/superadmin.ts` is the only file that may read `SUPERADMIN_EMAILS`**, and
  `src/lib/admin-queries.ts` is the only place unscoped queries live. Every other query in this
  codebase goes through `orgFilter()`; these deliberately do not, and the quarantine is what
  makes that visible in review rather than invisible in a diff.
- **A non-admin is redirected to `/library`, never 404'd.** The response must not confirm
  `/admin` exists. That is also why the nav link is gated server-side rather than rendered for
  everyone and hidden with CSS.

### 3c. TOSEC identity scan — DONE, on `feat/tosec-scan`, not merged

Identifies stored disk images by content hash against imported TOSEC data and corrects the
catalog's filename-derived titles. Spec: `docs/superpowers/specs/2026-08-31-tosec-identity-scan-design.md`.
Plan: `docs/superpowers/plans/2026-08-31-tosec-identity-scan.md` (11 tasks + a 12th added mid-flight).

**The measured result, which is the point of the whole increment: TOSEC recognises 28 of the
operator's 62 archive disks — 45.2%.** 55,932 entries are loaded from all seven Amiga `[ADF]` sets.

**Do not quote the database's own miss rate.** The blob corpus is dominated by e2e-generated
content with convincing TOSEC-style filenames, plus 129 blobs whose bytes were never in the object
store. Over that corpus the figure is 9.7% and it means nothing. Measure against a real archive
and exclude `unreadable`.

**The misses invert the spec's own argument about what to build next** — they are Workbench,
system and utility disks (`Install3_1_4.adf`, `Locale.adf`, `WHDLoad185.adf`, `Real_Amiga_Install.ADF`),
not games. Those are OFS/FFS disks a filesystem reader *can* read. See the spec's "What this
increment delivered" before planning the disk-content reader.

**Operator runbook:**

1. Download the Amiga TOSEC DATs. The complete pack holds 4,743 files for every system; only the
   seven `[ADF]` sets can ever match an ADF. The pack ships **Logiqx XML** despite every filename
   ending `_CM`.
2. `/admin/scan` → choose files. The input takes **several DATs at once**; they import
   sequentially and one bad file is skipped rather than aborting the run.
3. **Import everything first, then press Run now ONCE.** Each import clears every blob's match
   verdict, so sweeping between imports repeats a full re-match for nothing.
4. Press **Run now** until `unchecked` reaches 0. Each pass is bounded (~240 s) and resumable;
   the nightly cron at 03:00 continues on its own.

**`CRON_SECRET` is set in Vercel production** (2026-08-31). The cron route fails closed without it.

**Two known gaps, both found by the final review's own re-review and deliberately not fixed:**

- **A permanently-failing blob makes the sweeper hot-loop forever.** Phase 2 catches a per-blob
  error, logs it and moves on — deliberately *without* stamping `match_checked_at`, because a
  match failure is usually transient and stamping would misclassify it as decided. But once every
  other blob has drained, `todo` degenerates to just that blob, and every `sweep()` — cron and Run
  now alike — retries it for the whole 240 s budget and never reaches `done: true`. Nothing is
  corrupted; it simply never finishes and hammers the database nightly. The fix, if it ever fires,
  is a bounded retry or a distinguishable `match_state = 'error'` after N attempts. Watch for a
  `tosec-sweep: match failed for blob <sha>` line repeating in the logs.
- **`recordStatus()` in `src/lib/mount.ts` resolves a disk to its game using `disks.orgId` alone**,
  not double-scoped against `games.orgId` the way `src/lib/queries.ts` is. Since the merge now
  *preserves* org-drifted disks rather than letting the cascade delete them, the population of
  such rows grows rather than shrinks. `listDevices`' defensive join still stops a foreign title
  rendering, so this is the same already-tolerated class as the recorded "3 leftover devices",
  not a new leak — but it is worth a hardening pass.

**Things that will bite you here:**

- **NEVER re-derive `games.id` or `disks.id`.** `disks.id` descends from `games.id`, and
  `devices.desiredDiskId` is plain text with no foreign key that `readDesired` joins on. Re-keying
  makes that join return nothing, and in this protocol "no disk desired" **is eject** — a metadata
  scan would silently eject disks from real hardware, which disk-change spec §1 rule 1 forbids.
  Duplicates are merged on `(sortTitle, year)` instead, and `e2e/tosec-scan.spec.ts` has a test
  whose whole job is to catch a regression here.
- **Never clear a blob's hashes.** Both match resets touch only `match_checked_at`/`match_state`/
  `tosec_entry_id`. Hashing means re-reading every blob out of the object store; a content hash
  never changes.
- **`applyMatch` must run before the blob is stamped**, not after. Stamping first and failing
  leaves a blob permanently marked matched with the catalog never rewritten, and the sweeper's
  cursor never revisits it.
- **A human-edited game is never retitled *or merged away*.** `MACHINE_SOURCES` is `['filename',
  'tosec']`; anything else — including `NULL` — is protected, and two protected duplicates abort
  the merge rather than choosing between two human decisions.
- **`seedDisk()` must set `metadataSource: 'filename'`** to mirror real ingest. It once did not,
  and the resulting NULL is a row shape the app never produces, which silently made every
  TOSEC correction impossible in tests.
- **`stableId('tosec', setName, romName)` collides across tests reusing a set name.** That
  silently dropped one test's fixture via `onConflictDoNothing`. Give each test a distinct set name.
- **4 of 221 Amiga DATs contain duplicate rom names** (`Games - SPS` has 672 in 6,016), so the
  importer dedupes by id before upserting. Without it Postgres aborts the whole import.
- **Running the e2e suite globally invalidates the scan state.** `admin-scan.spec.ts` drives a
  real DAT through `/api/admin/tosec`, and `importDat()`'s reset is unscoped BY DESIGN (see the
  comment on that reset) -- it clears `match_checked_at`/`match_state`/`tosec_entry_id` on every
  blob with a verdict, not just the ones that DAT actually touches. So every suite run hands the
  whole blob corpus back to the sweeper: `unchecked` jumps from 0 to the full count, and the
  operator will see the scan "un-finishing" itself with no scan of their own having run.
  `cleanupTosec()` removes the e2e-seeded `tosec_entries` rows afterward, but it cannot restore
  the verdicts that reset threw away -- those are only recovered by pressing Run now again.

### 3d. OpenRetro enrichment — DONE, on `feat/openretro`, not merged

Enriches games with OpenRetro's publisher, developer, players, tags, chipset, prose and images,
matched by the SHA-1 the TOSEC scan already stores on every blob. Enrichment is **phase 3 of the
existing sweeper**, so it inherits the budget, cursor, cron and admin page.
Spec: `docs/superpowers/specs/2026-08-31-openretro-enrichment-design.md`.
Plan: `docs/superpowers/plans/2026-08-31-openretro-enrichment.md` (9 tasks).

**The measurement this increment exists to produce, and it is a disappointing one:**

| | disks recognised | rate |
|---|---|---|
| **TOSEC** | 28 / 61 | **45.9%** |
| **OpenRetro** | 4 / 61 | **6.6%** |

Measured exactly as TOSEC's 45% was — hash every local ADF in `adf-archive/`, look the SHA-1 up
directly. **OpenRetro knows nothing TOSEC does not**; it is a strict subset on this archive. The
4 disks are all Project-X (1992)(Team 17) and resolve to a single game. 33 disks neither knows.

**Why, and it is structural rather than bad luck.** A variant's `file_list` holds 418,539 files
across the real sync but only 19,483 are named `*.adf`; 190,425 have no extension at all, because
they are the individual files inside a WHDLoad install. OpenRetro's strength is file-level WHDLoad
content, not whole-disk ADF dumps. Only **14,850 of 175,282 distinct sha1s are ADFs**, so 92% of
the index could never match anything this app is able to store — the importer now filters to
`*.adf` for exactly that reason, which cut the table from 194,913 rows to 14,866 and the import
from 120 s to 13 s while losing no coverage.

**The lever nobody has pulled: match on TOSEC identity, not content hash.** 28 archive disks carry
a canonical TOSEC title and year, and OpenRetro holds 3,697 named games. Matching on identity
rather than digest would plausibly reach most of them instead of four. It trades exactness for a
title match, so it needs its own design and its own ambiguity rules — but it is the single change
that would make this increment pay for itself. The operator was shown the 6.6% and chose to ship
as built and record it, rather than expand scope here.

**Measured storage cost:** the one reachable game stored **7 images totalling 1,498,148 bytes
(1.43 MB)** — a 393 KB cover plus a title screen and five screenshots, averaging 214 KB each.
That is the `?size=400` resize doing its job; at full resolution the cover alone was ~1 MB.
Extrapolating, a library where OpenRetro recognised everything would cost roughly 1.5 MB per
title. The admin page shows the running total in MB so it never becomes a surprise.

**Two caveats that will mislead someone later:**

- **`openretro_images.sha1` does NOT verify the stored bytes.** It is OpenRetro's digest of the
  FULL-SIZE original, while what is stored is the `?size=400` resize — different bytes entirely.
  That inverts this codebase's usual rule, where `blobs.sha256` is re-read and re-hashed to prove
  the store holds what it claims. Here the digest is an identifier only, and anything that tries
  to "verify" an image against it will fail every row.
- **The e2e suite really does fetch from openretro.org**, despite no test asking it to. The specs
  seed their own data and never reach a third party — but `/api/admin/scan` sweeps the WHOLE live
  database, which now holds the real 3,697-entry import, so any spec that presses Run now enriches
  the real blobs and fetches their images. It is self-limiting (they are stamped afterward and
  images are never re-fetched) and it cost 7 images once. Re-importing `Amiga.sqlite` resets every
  enrichment verdict and will make it happen again.
- **The same `/api/admin/scan` sweep also runs the Demozoo match and screenshot phases, and
  the screenshot phase really does fetch from media.demozoo.org** (see 3af) — same shape as the
  OpenRetro caveat above: any e2e spec that presses Run now over the live database walks the
  Demozoo phases too, within the existing 60/hour politeness cap. 28 images were stored this
  way on 2026-09-14.

**Operator runbook:**

1. Run FS-UAE Launcher once and let it sync, producing `Amiga.sqlite`.
2. `/admin/scan` → **Import OpenRetro metadata**. One file; a full import takes ~13 s.
3. Press **Run now** until `enrich-unchecked` reaches 0. Image fetching is capped at 40 per run
   by design, so a first pass over a large library takes several runs or several nights.

**Things that will bite you here:**

- **`_type` is the STRING `"1"`/`"2"`, never the number.** A `=== 1` comparison matches 0 of
  21,440 rows. The plan's own fixture wrote numbers, so its test passed while the real file
  yielded nothing at all — the reader was only correct once it was run against `Amiga.sqlite`.
- **`game.data` is zlib-DEFLATE (`789c`), not gzip.** A gunzip-based reader throws.
- **`game.uuid` is a 16-byte BLOB; `parent_uuid` inside the JSON is a hyphenated string.**
  Without converting between them every variant silently orphans and nothing ever matches.
- **Screenshots 6-8 are `__screen6_sha1`**, with a leading double underscore. 415 games have them.
- **`?size=400` resizes server-side** (381,535 bytes versus 1,029,484). **`?width=` is silently
  ignored** and serves full size; `?w=` returns 500. Getting the name wrong costs 3x the storage.
- **The Blob store is PRIVATE.** `access: 'public'` is refused outright — "Cannot use public
  access on a private store" — and making it public to suit cover art would make every ADF in it
  publicly addressable, which is the boundary `/api/device/image` exists to enforce. Images are
  stored private and streamed by `/api/images/<sha1>`; no presigned URL ever reaches the DOM.
- **A broken `<img>` is still a visible element.** The first version of the image e2e passed
  while every single image fetch was failing. A test that asserts on an image must also assert
  the route serves the bytes.
- **`hol_url` is on the parent record** (3,634 of 3,697 entries), so a later Hall of Light
  increment gets an exact id and needs no title matching at all.
- **`metadataSource` is never written by enrichment.** It owns row IDENTITY, which is still
  TOSEC's; stamping it `openretro` would lock TOSEC out of correcting the title forever.
  `factsSource`/`proseSource` record what enrichment wrote without claiming the row.

### 3e. The e2e suite now cleans up after itself — DONE 2026-09-01, merged and live

**`e2e/global-teardown.ts`, wired into `playwright.config.ts`.** Before it, one suite run left
~70 users, orgs, games and disks in the live database permanently, and **4,600 rows had
accumulated since 2026-08-23**. A full run now leaves the database exactly as it found it.

**Backfilled once:** 4,601 test users, 66 games, 4,201 invites, 72 blobs and 72 stored objects
removed; 485 stale admin sessions cleared. The operator's account and its 5 games were verified
intact before and after. Baseline is now 2 users, 5 games, 10 disks, 10 blobs, 0 live codes.

**The security-relevant half was the invite codes, not the row count.** Registration is
invite-only — that is what bounds the ingest existence oracle (D13) — and **73 unconsumed,
unexpired codes were live**. Neither population was reachable by any cascade: 4,144 were minted
under placeholder org ids that no `auth.organization` row matches (`mintInviteCode` uses
`e2e-seed-org`, because its callers have no org yet), and 14 belonged to the kept
`admin@example.test` account, which survives on purpose so its invites survived with it. The
teardown matches on **"the org does not exist"** rather than a list of known placeholder names,
so a future helper inventing its own id is caught automatically.

**Things worth knowing:**

- **The safety boundary is the email domain and nothing else.** Every account the suite creates
  is `@example.test`; the operator's is not. **Never widen that predicate.**
- It reuses **`deleteUserCascade`** from `src/lib/admin-delete.ts` — the app's own cascade,
  already covered by `admin-delete.spec.ts` — so the teardown cannot drift from real behaviour.
- **Blobs are handled separately and deliberately**, because that cascade refuses to touch a
  global content-addressed table (26 blobs are shared across orgs, and there is a test for it).
  Only blobs *nothing* references anywhere are reclaimed; the rule is a pure tested function in
  `src/lib/blob-gc.ts`, not a SQL predicate no test can exercise. **That function is also what a
  future "blob garbage collection" increment should build on.**
- **Stored objects are removed before their rows.** A removed object with a surviving row shows
  up as `unreadable` and a human can see it; a deleted row whose object survives is invisible
  forever, because the sha is the only handle on it.
- **A test was passing only because of the leak.** `admin-guard.spec.ts`'s "paging forward"
  clicks Next and needs a second page of users; 4,600 leftover accounts guaranteed one, so the
  spec never created what it asserted on. Fixing the leak broke it. It now seeds `PER_PAGE + 5`
  rows itself. **If another spec starts failing after a clean run, suspect this shape first.**
- The one-time backfill took **32 minutes** (4,601 sequential cascades over neon-http). A normal
  teardown handles ~120 users and adds a few seconds.
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

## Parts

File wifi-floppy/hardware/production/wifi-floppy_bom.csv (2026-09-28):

Designator | Footprint | Quantity | Value | LCSC Part #
BZ1 | Buzzer_TDK_PS1240P02BT_D12.2mm_H6.5mm | 1 | Buzzer | C2687681
C1 | 1206 | 1 | 100nF
C3 | 1206 | 1 | 10uF
D1 | D_SMA_Handsoldering | 1 | SS14
D2 | 1206 | 1 | LED | C49018
J1 | IDC-Header_2x17_P2.54mm_Vertical | 1 | Conn_02x17_Odd_Even | DNP
J2 | PinHeader_1x04_P2.54mm_Horizontal | 1 | Conn_01x04 | DNP
J3, J4 | PinHeader_1x04_P2.54mm_Vertical | 2 | Conn_01x04 | DNP
Q1, Q2, Q3, Q4, Q5, Q6, Q7, Q8 | SOT-23 | 8 | BSS138
R1, R11, R2, R3, R4, R5, R6, R7, R8, R9 | 1206 | 10 | 1k | C1469
R10 | 1206 | 1 | 10k | C1489
R12 | 1206 | 1 | 22 | C2925020
U1 | RaspberryPi_Pico_W_SMD_HandSolder | 1 | RaspberryPi_Pico_W | DNP
U2 | SOIC-20W_7.5x15.4mm_P1.27mm | 1 | 74LVC541A | DNP

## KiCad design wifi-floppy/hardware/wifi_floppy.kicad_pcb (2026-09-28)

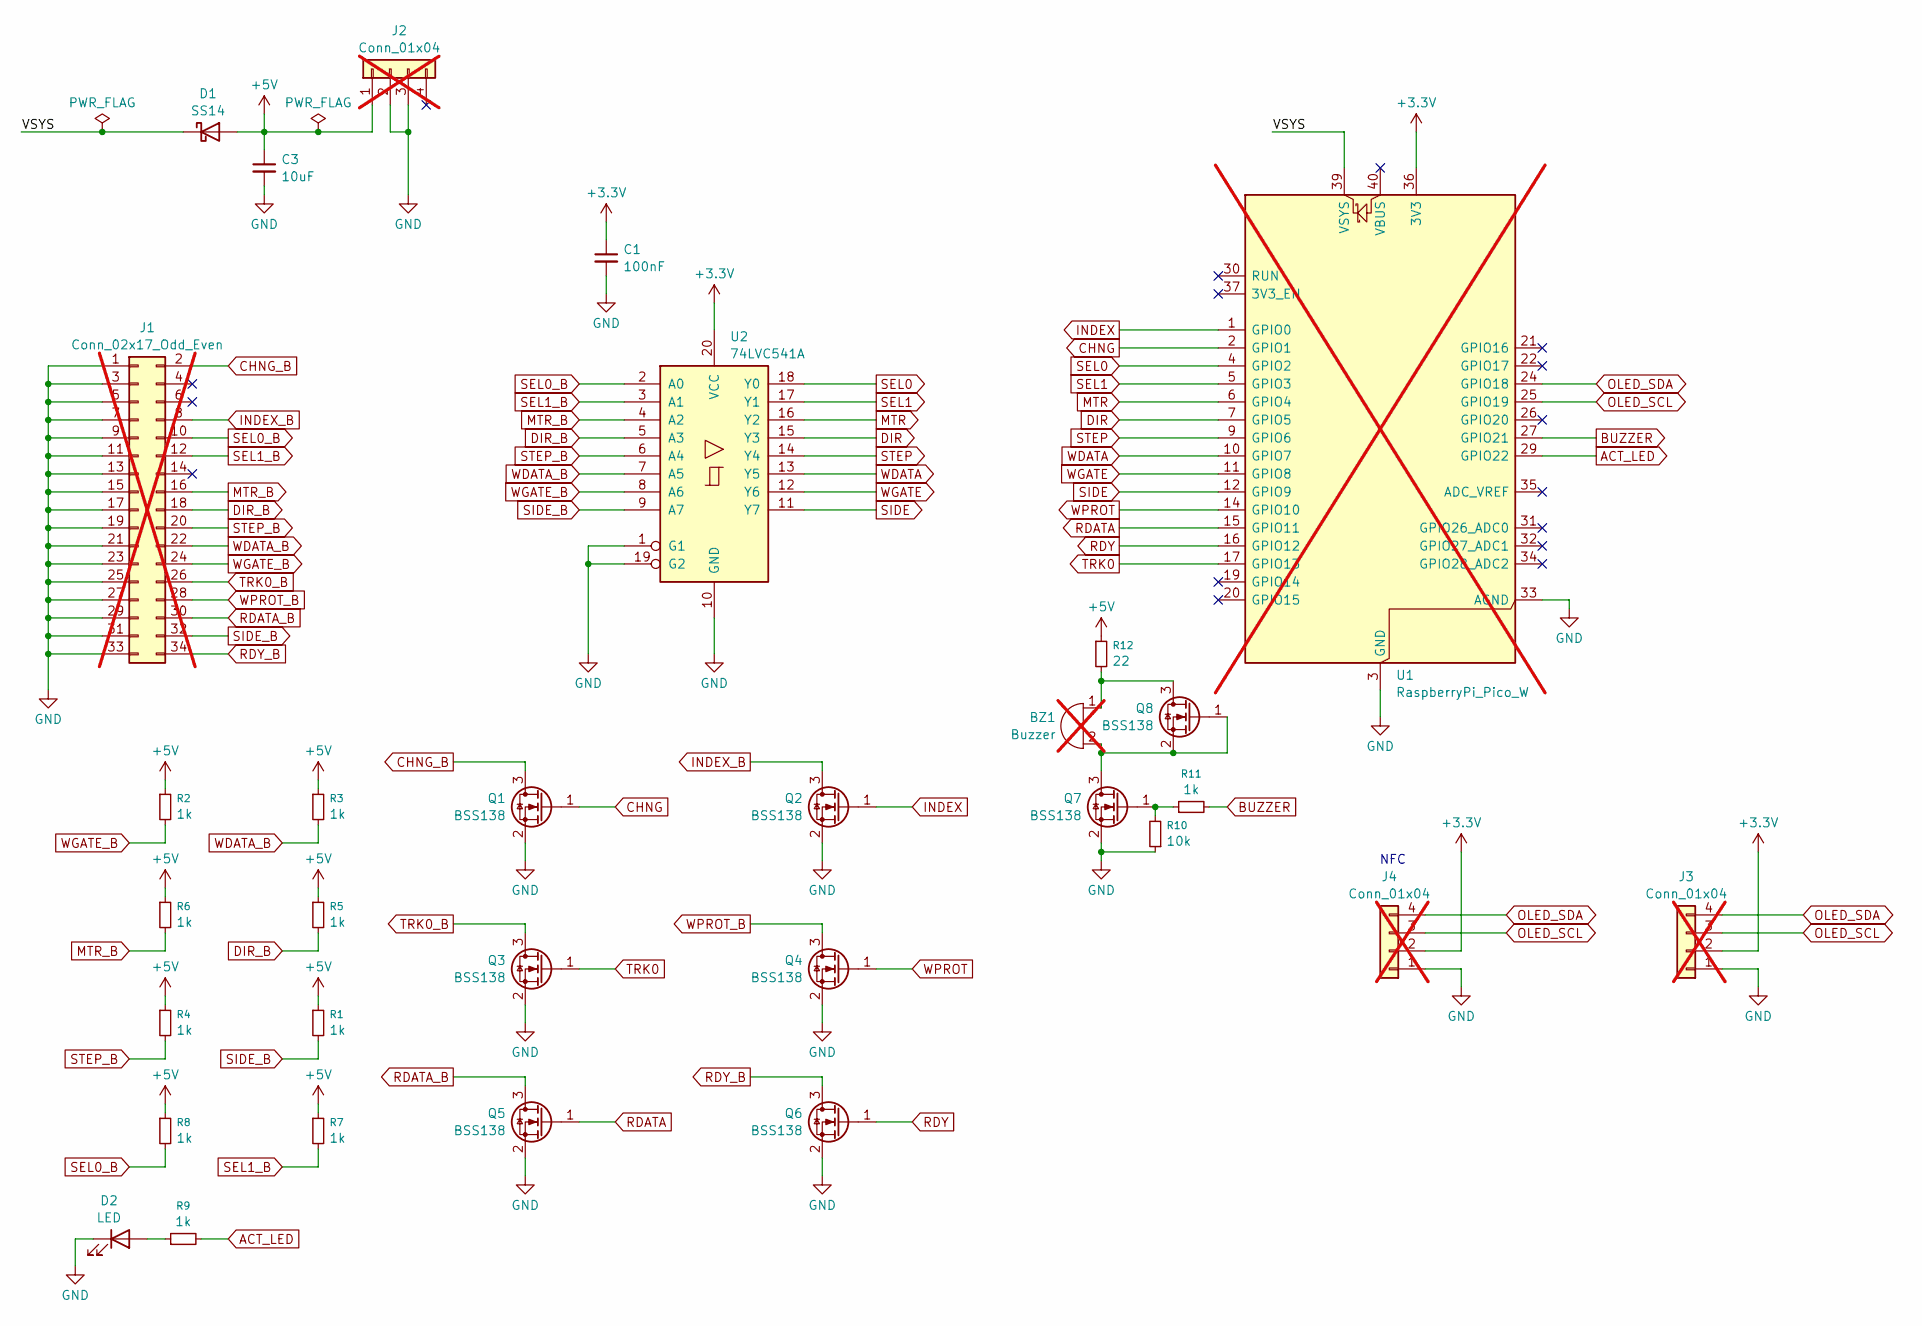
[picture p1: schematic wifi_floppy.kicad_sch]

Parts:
BZ1: Buzzer; Buzzer_TDK_PS1240P02BT_D12.2mm_H6.5mm; LCSC C2687681; not fitted
C1: 100nF; C_1206_3216Metric_Pad1.33x1.80mm_HandSolder
C3: 10uF; C_1206_3216Metric_Pad1.33x1.80mm_HandSolder
D1: SS14; D_SMA_Handsoldering
D2: LED; LED_1206_3216Metric_Pad1.42x1.75mm_HandSolder; LCSC C49018
J1: Conn_02x17_Odd_Even; IDC-Header_2x17_P2.54mm_Vertical; LCSC DNP; not fitted
J2: Conn_01x04; PinHeader_1x04_P2.54mm_Horizontal; LCSC DNP; not fitted
J3, J4: Conn_01x04; PinHeader_1x04_P2.54mm_Vertical; LCSC DNP; not fitted
Q1, Q2, Q3, Q4, Q5, Q6, Q7, Q8: BSS138; SOT-23
R1, R2, R3, R4, R5, R6, R7, R8, R9, R11: 1k; R_1206_3216Metric_Pad1.30x1.75mm_HandSolder; LCSC C1469
R10: 10k; R_1206_3216Metric_Pad1.30x1.75mm_HandSolder; LCSC C1489
R12: 22; R_1206_3216Metric_Pad1.30x1.75mm_HandSolder; LCSC C2925020
U1: RaspberryPi_Pico_W; RaspberryPi_Pico_W_SMD_HandSolder; LCSC DNP; not fitted
U2: 74LVC541A; SOIC-20W_7.5x15.4mm_P1.27mm; LCSC DNP

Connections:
+3.3V: C1.1, J3.2, J4.2, U1.36 (3V3), U2.20 (VCC)
+5V: C3.1, D1.2 (A), J2.1, R1.1, R2.1, R3.1, R4.1, R5.1, R6.1, R7.1, R8.1, R12.1
/VSYS: D1.1 (K), U1.39 (VSYS)
ACT_LED: R9.2, U1.29 (GPIO22)
BUZZER: R11.2, U1.27 (GPIO21)
CHNG: Q1.1 (G), U1.2 (GPIO1)
CHNG_B: J1.2, Q1.3 (D)
DIR: U1.7 (GPIO5), U2.15 (Y3)
DIR_B: J1.18, R5.2, U2.5 (A3)
GND: C1.2, C3.2, D2.1 (K), J1.1, J1.3, J1.5, J1.7, J1.9, J1.11, J1.13, J1.15, J1.17, J1.19, J1.21, J1.23, J1.25, J1.27, J1.29, J1.31, J1.33, J2.2, J2.3, J3.1, J4.1, Q1.2 (S), Q2.2 (S), Q3.2 (S), Q4.2 (S), Q5.2 (S), Q6.2 (S), Q7.2 (S), R10.1, U1.3 (GND), U1.8 (GND), U1.13 (GND), U1.18 (GND), U1.23 (GND), U1.28 (GND), U1.33 (AGND), U1.38 (GND), U2.1 (G1), U2.10 (GND), U2.19 (G2)
INDEX: Q2.1 (G), U1.1 (GPIO0)
INDEX_B: J1.8, Q2.3 (D)
MTR: U1.6 (GPIO4), U2.16 (Y2)
MTR_B: J1.16, R6.2, U2.4 (A2)
unnamed: BZ1.1 (+), Q8.3 (D), R12.2
unnamed: BZ1.2 (-), Q7.3 (D), Q8.1 (G), Q8.2 (S)
unnamed: D2.2 (A), R9.1
unnamed: Q7.1 (G), R10.2, R11.1
OLED_SCL: J3.3, J4.3, U1.25 (GPIO19)
OLED_SDA: J3.4, J4.4, U1.24 (GPIO18)
RDATA: Q5.1 (G), U1.15 (GPIO11)
RDATA_B: J1.30, Q5.3 (D)
RDY: Q6.1 (G), U1.16 (GPIO12)
RDY_B: J1.34, Q6.3 (D)
SEL0: U1.4 (GPIO2), U2.18 (Y0)
SEL0_B: J1.10, R8.2, U2.2 (A0)
SEL1: U1.5 (GPIO3), U2.17 (Y1)
SEL1_B: J1.12, R7.2, U2.3 (A1)
SIDE: U1.12 (GPIO9), U2.11 (Y7)
SIDE_B: J1.32, R1.2, U2.9 (A7)
STEP: U1.9 (GPIO6), U2.14 (Y4)
STEP_B: J1.20, R4.2, U2.6 (A4)
TRK0: Q3.1 (G), U1.17 (GPIO13)
TRK0_B: J1.26, Q3.3 (D)
WDATA: U1.10 (GPIO7), U2.13 (Y5)
WDATA_B: J1.22, R3.2, U2.7 (A5)
WGATE: U1.11 (GPIO8), U2.12 (Y6)
WGATE_B: J1.24, R2.2, U2.8 (A6)
WPROT: Q4.1 (G), U1.14 (GPIO10)
WPROT_B: J1.28, Q4.3 (D)

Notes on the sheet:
NFC

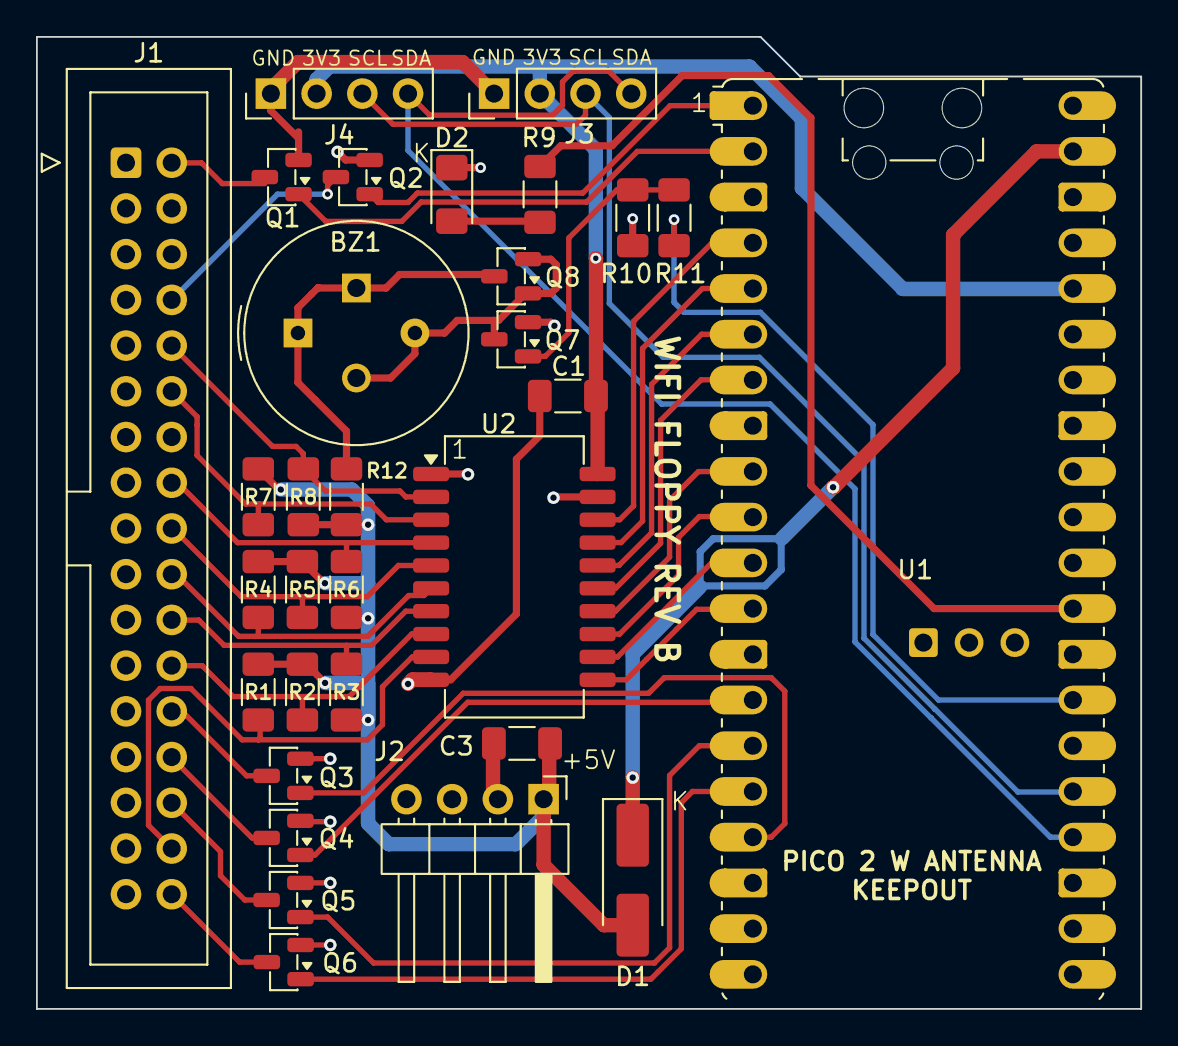
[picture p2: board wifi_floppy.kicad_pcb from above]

Board: 2 copper layers, 61.4 x 54.0 mm, 31 parts (0 on the bottom side), 40 nets.

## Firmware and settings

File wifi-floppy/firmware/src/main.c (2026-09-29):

// ---------------------------------------------------------------------------
// WiFi floppy emulator — Pico 2 W main.
// Core 0: floppy bus real-time (STEP/SEL ISRs, DMA feed, INDEX pulse).
// Core 1: WiFi + track streaming from the ADF webservice.
// ---------------------------------------------------------------------------
#include "pico/stdlib.h"
#include "pico/multicore.h"
#include "pico/cyw43_arch.h"
#include "pico/flash.h"
#include "pico/time.h"
#include "hardware/pio.h"
#include "hardware/dma.h"
#include "hardware/irq.h"
#include "floppy.pio.h"
#include "floppy_io.h"
#include "dskchg.h"
#include "bus_gate.h"
#include "bus_out.h"
#include "drive_id.h"
#include "track_cache.h"
#include "adf_mfm.h"
#include "psram_image.h"
#include "image_loader.h"
#include "transport.h"
#include "device_client.h"
#include "token_store.h"
#include "sntp_time.h"
#include "provisioning.h"
#include "config_store.h"
#include "portal_net.h"
#include "lwip/netif.h"   // default_route_str(): netif_default, see portal_stop()
#include <stdio.h>
#include "wf_log.h"
#include "activity_led.h"
#include "i2c_probe.h"
#include "ssd1306.h"
#include "display.h"
#include "nfc_reader.h"
#include "nfc_bus_i2c.h"
#include "nfc_handoff.h"
#include "nfc_ui.h"
// Generated at BUILD time by cmake/gen_version_header.cmake, so the string
// always matches the commit this image was compiled from.
#include "wifi_floppy_version.h"
#include "flux_capture.h"
#include "flux_bits.h"
#include "mfm.h"
#include "write_back.h"
#include "reinsert.h"
#include "swap_gate.h"
#include "uploader.h"
#include "fw_rom.h"
#include "fw_state.h"
#include "fw_trial.h"
#include "fw_update.h"       // fwu_*, and through it fw_offer/fw_verify/fw_stage/fw_apply
#include "hardware/psram.h"  // psram_check_address, for g_fw_stage below
#include "pico/rand.h"
#include "hardware/sync.h"   // __dmb(), for the display seqlock below
#include <string.h>
#include <stddef.h>          // ptrdiff_t, for __wrap__sbrk() below

// transport_tls.c is device-only (no host test exercises it, unlike every
// other file this task wires in), so it has no shared header of its own --
// see CMakeLists.txt's -Wl,-u,tls_transport comment for how it stays
// linked in regardless of whether anything referenced it yet. Declaring
// the one entry point here, now that this file is that "anything".
transport_t *tls_transport(void);
// Same file, same reason it has no header. Releases a kept TLS connection
// once it has sat idle past the point tls_connect() would reuse it -- the
// transport owns both the "when did it go idle" stamp and the cap, so this
// asks it rather than inferring either here. Called once per pass of core1's
// two waiting loops; see release_kept_connection() below for the other,
// unconditional half.
bool tls_release_if_unreusable(void);

// ---------------------------------------------------------------- display
//
// WHERE THIS RUNS, and why it is not the obvious answer.
//
// Core1 owns the network, so it is core1 that knows DOWNLOAD and LOADED and
// the disk's name -- which makes "render on core1" the first idea anyone has,
// including me. It is wrong: core1 blocks for tens of seconds inside dc_step's
// long poll, and the TRACK COUNTER would freeze mid-seek for exactly that
// long. The counter is core0 state (cur_cyl, set by the STEP ISR), so core0 is
// what must drive the panel.
//
// But core0 cannot afford a frame. Its service loop turns over every 1 ms and
// a full 128x32 frame is 512 bytes -- ~11 ms at 400 kHz -- which would stall
// the floppy exactly as the flood of USB writes did on 2026-09-10. So:
//
//   * the framebuffer lives in RAM and is composed by display.c, which is
//     pure CPU work and pure C (host-tested, see test/test_display.c);
//   * only CHANGED bytes are sent, and only a bounded slice per iteration.
//
// Core1 publishes what it knows through a seqlock; core0 reads it, adds the
// track counter, and pumps. Core1 never touches the panel.
//
// Also load-bearing: nothing here drains wf_log. A display fed from the log
// would COMPETE with the USB console for records (wf_log_drain consumes), so
// attaching a terminal would blank the screen. It reads state directly.

// Bytes of payload per pump call. The cost of a call is (n + 8) bytes at
// 400 kHz and ~9 bits per byte -- 8 being the window commands and the control
// byte -- so 12 is ~450 us and 96 is ~2.3 ms.
//
// Two budgets because the real-time duty is not constant: while a disk is
// mounted the Amiga can be reading and core0 must stay responsive to STEP;
// with nothing mounted there is no floppy traffic at all and a slow, pretty
// redraw costs nobody anything. The seek deadline it must respect is head
// settle, ~15 ms, not the 1 ms loop period.
#define DISP_BUDGET_MOUNTED 12
#define DISP_BUDGET_IDLE    96

// How long the lemming holds each frame. ~8 steps a second, which is a brisk
// walk and not a twitch. Cheap by construction: a frame change dirties only
// the sprite's own 8 columns of one page (there is a test for that), so a step
// is a single pump call even at the mounted budget.
#define LEMMING_STEP_MS 120

static display_t  g_disp;
static uint8_t    g_panel_addr;          // 0 == no panel answered at boot

static bool panel_blit(void *ctx, int page, int col, const uint8_t *b, int n) {
    (void)ctx;
    return ssd1306_blit(g_panel_addr, page, col, b, n);
}

// The published half: written by core1, read by core0. `g_ui_seq` is odd
// while the strings are being written, so a reader can tell it caught a torn
// update and simply try again on its next 1 ms turn -- a display is the one
// consumer for which "skip this frame" is a complete and correct answer.
static volatile uint32_t g_ui_seq;
static char g_ui_title[DISP_TITLE_MAX + 1];
static char g_ui_detail[DISP_DETAIL_MAX + 1];
static volatile int g_ui_status = DS_BOOT;
static volatile int g_ui_bars   = -1;
static volatile int g_ui_pct    = -1;
// Set from the SAME expression that drives the WPROT pin, never computed
// separately: a pencil that disagreed with the pin would be worse than no
// pencil, because it would be believed.
static volatile bool g_ui_writable = false;
// Same idea as g_ui_writable: set from up_sync(&up) at the same moment, on
// core1, and read by core0 in ui_snapshot below -- never computed from a
// cast, since up_sync_t and disp_sync_t are converted by a switch (see
// core1_main's WPROT block).
static volatile int g_ui_sync = DISP_SYNC_SYNCED;
// A tap's line (nfc_ui.h), published by core1 with the time it was published
// and a count of publications. core0 shows it OVER g_ui_detail while it is
// under NFC_UI_LINE_MS old (nfc_tag_clock_live, nfc_ui_detail), so the
// observer's line underneath is never overwritten and the revert is on time
// even while core1 sits in a 25 s held poll. The count is what lets core0 end
// a line for good: an age alone comes back when the ms clock wraps.
static char g_ui_tag[NFC_UI_LINE_BYTES];
static uint32_t g_ui_tag_at;
static uint32_t g_ui_tag_n;

static void ui_publish(disp_status_t st, const char *title, const char *detail, int pct) {
    g_ui_seq++;                     // odd: writing
    __dmb();
    if (title)  snprintf(g_ui_title,  sizeof g_ui_title,  "%s", title);
    if (detail) snprintf(g_ui_detail, sizeof g_ui_detail, "%s", detail);
    __dmb();
    g_ui_seq++;                     // even: settled
    g_ui_status = (int)st;
    g_ui_pct    = pct;
}

/** core1: show `line` on the detail line for NFC_UI_LINE_MS from `now`. */
static void ui_publish_tag(const char *line, uint32_t now) {
    g_ui_seq++;                     // odd: writing
    __dmb();
    snprintf(g_ui_tag, sizeof g_ui_tag, "%s", line);
    g_ui_tag_at = now;
    g_ui_tag_n++;
    __dmb();
    g_ui_seq++;                     // even: settled
}

/** Copy the published state, and the tap line with its time and count. False
 *  means "torn, ask again" -- never a stale half-string handed to the renderer. */
static bool ui_snapshot(display_state_t *s, char tag[NFC_UI_LINE_BYTES], uint32_t *tag_at,
                        uint32_t *tag_n) {
    uint32_t a = g_ui_seq;
    __dmb();
    if (a & 1u) return false;
    memset(s, 0, sizeof *s);
    s->status   = (disp_status_t)g_ui_status;
    s->bars     = g_ui_bars;
    s->pct      = g_ui_pct;
    s->writable = g_ui_writable;
    s->sync     = (disp_sync_t)g_ui_sync;
    // core1 recomputes g_ui_sync only between requests, and a long poll holds
    // it for up to 25 s. A write core0 applied meanwhile must not read as
    // "synced": that is the one question the cloud answers ("can I switch
    // off now?"). core0 set these dirty flags itself, so it sees them at once.
    // Found on the bench 2026-09-19: ~6 s of a plain cloud over unsent writes.
    if (s->sync == DISP_SYNC_SYNCED && psram_image_dirty_count(psram_active_slot()) > 0)
        s->sync = DISP_SYNC_PENDING;
    memcpy(s->title,  g_ui_title,  sizeof s->title);
    memcpy(s->detail, g_ui_detail, sizeof s->detail);
    s->title[DISP_TITLE_MAX]   = '\0';
    s->detail[DISP_DETAIL_MAX] = '\0';
    memcpy(tag, g_ui_tag, NFC_UI_LINE_BYTES);
    tag[NFC_UI_LINE_BYTES - 1] = '\0';
    *tag_at = g_ui_tag_at;
    *tag_n  = g_ui_tag_n;
    __dmb();
    return g_ui_seq == a;
}

/** Just the dotted quad, for the panel's bottom line. default_route_str() is
 *  the diagnostic form ("w00 ip=..."), which is right for a console log and
 *  wrong for 21 characters of glass. Takes the lwIP lock, so core1 only --
 *  never from core0's service loop, and never from an interrupt. */
static const char *ip_str(void) {
    static char buf[20];
    cyw43_arch_lwip_begin();
    struct netif *nif = netif_default;
    snprintf(buf, sizeof buf, "%s", nif ? ip4addr_ntoa(netif_ip4_addr(nif)) : "no route");
    cyw43_arch_lwip_end();
    return buf;
}

/** RSSI to arcs. The thresholds are the ordinary ones for 2.4 GHz: -60 dBm is
 *  a strong link, -80 is the edge of usable. Below that the glyph shows a bare
 *  dot, which is honest -- it is associated, and barely. */
static int rssi_bars(int rssi) {
    if (rssi == 0)    return -1;      // not associated at all
    if (rssi >= -60)  return 3;
    if (rssi >= -70)  return 2;
    if (rssi >= -80)  return 1;
    return 0;
}

// Core1's view of the state machine, turned into words. Called from inside
// dc_step -- including from the image read loop -- so it must do nothing but
// format and store, which is all ui_publish does.
static void ui_observe(void *ctx, const dc_obs_t *o) {
    (void)ctx;
    char detail[DISP_DETAIL_MAX + 1];
    switch (o->kind) {
    case DC_OBS_FETCH_BEGIN:
        ui_publish(DS_DOWNLOAD, o->title[0] ? o->title : "Fetching", "", 0);
        break;
    case DC_OBS_FETCH_PROGRESS: {
        int pct = o->total ? (int)((uint64_t)o->got * 100u / o->total) : -1;
        snprintf(detail, sizeof detail, "%lu of %lu KB",
                 (unsigned long)(o->got / 1024u), (unsigned long)(o->total / 1024u));
        ui_publish(DS_DOWNLOAD, NULL, detail, pct);
        break;
    }
    case DC_OBS_VERIFY:
        ui_publish(DS_VERIFY, NULL, "checking image", -1);
        break;
    case DC_OBS_MOUNTED:
        // "Disk 1/2" only when there is more than one -- on a single-disk
        // game it is noise, and the line is 21 characters wide.
        if (o->disk_count > 1)
            snprintf(detail, sizeof detail, "Disk %lu/%lu %s",
                     (unsigned long)o->disk_no, (unsigned long)o->disk_count, o->label);
        else
            snprintf(detail, sizeof detail, "%s", o->label);
        ui_publish(DS_LOADED, o->title[0] ? o->title : "Disk mounted", detail, -1);
        break;
    case DC_OBS_EJECTED:
        ui_publish(DS_READY, "No disk", "", -1);
        break;
    }
}

// Write-back is on unconditionally (write-back spec piece 2b): a whole,
// clean captured track is applied to the board's copy of the disk AND
// uploaded to the server by core1's uploader (uploader.c, driven from
// core1_main). WPROT follows the server's writeProtected flag, forced
// asserted whenever nothing is mounted or the uploader itself has been
// refused a write (up_forces_wprot) -- see core1_main's WPROT comment for
// how this is wired.

/*
 * WF_VERIFY_TRACKS -- after every mount, read each of the 160 tracks back out
 * of PSRAM and DECODE it the way the Amiga will, checking that all eleven
 * sectors recover with valid header and data checksums.
 *
 * Diagnostic, off by default (-DWF_VERIFY_TRACKS=1). It exists because an
 * Amiga reported an unreadable track that this board had demonstrably served
 * whole, from an image proven byte-identical to the upload, encoded to MFM
 * proven byte-identical to Greaseweazle on all 160 tracks. Everything software
 * could check had been checked EXCEPT the copy actually sitting in PSRAM at the
 * moment of serving -- image_loader verifies it once as it arrives and nothing
 * looks at it again.
 *
 * Bounded: ONE track per service-loop iteration, so a sweep costs ~160
 * iterations rather than one long stall in the loop that feeds the floppy.
 */
#ifndef WF_VERIFY_TRACKS
#define WF_VERIFY_TRACKS 0
#endif

/*
 * WF_BUS_SNIFF -- log every change on the eight bus inputs, in exact order,
 * from the bus_sniff PIO program. Diagnostic, off by default
 * (-DWF_BUS_SNIFF=1). While it is on, the GPIO ISR's own SEL and SIDE traces
 * are suppressed: they carry the same edges, in pin order and sampled late,
 * and would only compete with these for log slots.
 */
#ifndef WF_BUS_SNIFF
#define WF_BUS_SNIFF 0
#endif

static PIO  pio = pio0;
static uint sm_out, sm_in;
static int  dma_ch;

static volatile int  cur_cyl   = 0;
static volatile int  cur_side  = 0;
static volatile int  want_track = -1;      // core0 -> core1 request
static volatile bool track_live = false;
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
int main(void) {
    // FIRST, before stdio, core1, or any PSRAM user: a trial that proved
    // itself last boot is bought here, single-core (fw_rom.c, fix round 4).
    fw_rom_boot_early(WF_FIRMWARE_VERSION);
    // THEN PSRAM, on every boot, before anything that touches it (the log
    // ring is SRAM; track_cache_init/psram_image_init and everything after
    // use PSRAM). The SDK's pre-main PSRAM init is skipped
    // (PICO_RUNTIME_SKIP_INIT_PSRAM=1) because the ROM buy above hangs,
    // measured, whenever PSRAM is configured. IRQs off around it: it runs
    // flash_start_xip() (XIP briefly down), which pre-main init ran with no
    // IRQ sources live; here the default alarm pool's timer IRQ already is.
    {
        uint32_t irq = save_and_disable_interrupts();
        runtime_init_setup_psram();
        restore_interrupts(irq);
    }
    stdio_init_all();
    wf_log_init();
    wf_logf(WF_INFO, "wifi-floppy boot: %s", PICO_BOARD);

    // inputs. PIN_WDATA belongs here too even though only PIO reads it: an
    // RP2350 pad stays isolated from reset until gpio_set_function() clears
    // ISO, and until then PIO reads it as 0 whatever the pin carries. Left
    // out, WDATA read low in every sample, with 1k to +5V on J1 pin 22 and
    // the Amiga idle (2026-09-15).
    const uint ins[] = {PIN_SEL0, PIN_SEL1, PIN_MTR, PIN_DIR,
                        PIN_STEP, PIN_WDATA, PIN_WGATE, PIN_SIDE};
    for (unsigned i = 0; i < count_of(ins); i++) {
        gpio_init(ins[i]); gpio_set_dir(ins[i], GPIO_IN);
    }

    // Status outputs (FET gates): handed to the status_gate PIO, which drives
    // them only while SEL0 is asserted -- so AFTER the inputs, or the gate's
    // first loops read SEL0's still-isolated pad as 0, "selected". From here
    // on bus_out_set() is the only way to change one -- gpio_put() on these
    // pads does nothing.
    //
    // TRK0: powered on at cyl 0. WPROT: a boot-time default, before core1 has
    // even started, let alone learned whether a disk is mounted or what the
    // server says about it -- core1's main loop is the only thing that writes
    // WPROT after this (see its WPROT comment), but "asserted" is the only
    // safe value to boot with regardless: read-only until proven otherwise
    // beats writable by default.
    bus_out_init(bus_pio, (1u << PIN_TRK0) | (1u << PIN_WPROT));

    dskchg_init();
    track_cache_init();

    // Both are hand-wired bring-up aids on unrouted header pins and both are
    // no-ops with nothing attached, so neither is conditional: a board with no
    // LED and no panel simply logs that it found no panel.
    led_init();
    // Three blinks, scheduled not blocked. With no Amiga connected there is no
    // floppy traffic at all, so this is the only thing that distinguishes a
    // working LED from a backwards one before the cable goes on.
    led_selftest(3);
    {
        uint8_t panel = 0;
        i2c_probe_bus(&panel);
        // Only when a panel actually answered: a missing display must cost
        // nothing, and must certainly not put bounded-but-real bus writes in
        // front of a board that is trying to boot.
        if (panel != 0 && ssd1306_selftest(panel)) {
            // The self-test leaves the frame-and-X on the glass. Clear it, or
            // the pump's first update would show the test pattern through
            // every byte the new frame happens to leave blank -- display.c's
            // shadow starts all-zero and only sends what DIFFERS, which is
            // the whole reason a track step costs a few bytes and not a frame.
            ssd1306_clear(panel);
            g_panel_addr = panel;
            display_init(&g_disp, panel_blit, NULL);
            ui_publish(DS_BOOT, "wifi-floppy", "starting", -1);
        }
        // The tag reader, on the bus i2c_probe_bus just initialised: 400 kHz
        // if a panel answered, else still the probe's 100 kHz, left as is.
        // Nothing touches the chip here -- the first nfc_step() is the
        // boot-time presence check, in the service loop's display slot.
        nfc_bus_t nfc_bus;
        nfc_bus_i2c(&nfc_bus);
        nfc_init(&g_nfc, &nfc_bus, clock_ms);
    }
    // psram_image_init() runs inside track_cache_init() and its bool result is
    // discarded there. Say it out loud, because PSRAM is the one part of this
    // board no footprint check and no host test can vouch for: a pin-compatible
    // module WITHOUT the PSRAM this design needs fits U1 perfectly, and the only
    // symptom is that image_parse_begin() goes straight to its error state and
    // every single fetch fails -- silently, forever, on a board that otherwise
    // associates, registers and polls perfectly.
    {
        bool ok = psram_image_available();
        wf_logf(ok ? WF_INFO : WF_ERR, "psram: %s (%u KB needed for %d slots)",
                ok ? "available" : "NOT AVAILABLE -- every image fetch will fail",
                (unsigned)((size_t)SLOT_COUNT * NUM_TRACKS * TRACK_MAX_BYTES / 1024u),
                SLOT_COUNT);
    }
    // The firmware-update stage (2b) sits after the image slots in PSRAM.
    // Checked here -- after runtime_init_setup_psram() above -- and before
    // core1 launches, which is the only reader of g_fw_stage_ok.
    g_fw_stage_ok = psram_check_address(&g_fw_stage[FW_MAX_IMAGE_BYTES - 1]);
    if (!g_fw_stage_ok)
        wf_logf(WF_ERR, "fw: the update stage is not backed by PSRAM -- updates disabled");

    // PIO
    uint off_out = pio_add_program(pio, &flux_out_program);
    sm_out = pio_claim_unused_sm(pio, true);
    flux_out_program_init(pio, sm_out, off_out, PIN_RDATA, PIN_SEL0);
    pio_sm_set_enabled(pio, sm_out, true);

    uint off_in = pio_add_program(pio, &flux_in_program);
    sm_in = pio_claim_unused_sm(pio, true);
    flux_in_program_init(pio, sm_in, off_in, PIN_WDATA);
    // Claims a DMA channel and points it at sm_in's RX FIFO. The state machine
    // stays DISABLED until WGATE says the Amiga is writing -- see
    // flux_capture_arm().
    flux_capture_init(pio, sm_in);
    // (enabled when WGATE asserts; write path TODO)

    dma_ch = dma_claim_unused_channel(true);
    irq_set_exclusive_handler(DMA_IRQ_0, dma_irq);
    irq_set_enabled(DMA_IRQ_0, true);

    // STEP and DIR are not GPIO interrupts: see step_dir in floppy.pio. This
    // shares pio2 with the CYW43 driver, which claims a state machine there
    // when core1 brings the radio up -- its search starts at pio2 (see
    // bus_pio above), and "pio claims" in the log says where it landed.
    uint off_step = pio_add_program(step_pio, &step_dir_program);
    step_sm = pio_claim_unused_sm(step_pio, true);
    step_dir_program_init(step_pio, step_sm, off_step, PIN_STEP, PIN_SEL0);
    pio_set_irq0_source_enabled(step_pio, pio_get_rx_fifo_not_empty_interrupt_source(step_sm),
                                true);
    irq_set_exclusive_handler(pio_get_irq_num(step_pio, 0), step_pio_isr);
    irq_set_enabled(pio_get_irq_num(step_pio, 0), true);
    pio_sm_set_enabled(step_pio, step_sm, true);

    // MTR is latched on SEL0's falling edge (sel_mtr), not followed edge by
    // edge: MTR is shared, and only the selected drive takes it.
    uint off_mtr = pio_add_program(bus_pio, &sel_mtr_program);
    mtr_sm = pio_claim_unused_sm(bus_pio, true);
    sel_mtr_program_init(bus_pio, mtr_sm, off_mtr, PIN_SEL0, PIN_MTR);
    pio_set_irq0_source_enabled(bus_pio, pio_get_rx_fifo_not_empty_interrupt_source(mtr_sm),
                                true);
    irq_set_exclusive_handler(pio_get_irq_num(bus_pio, 0), mtr_pio_isr);
    irq_set_enabled(pio_get_irq_num(bus_pio, 0), true);
    pio_sm_set_enabled(bus_pio, mtr_sm, true);

#if WF_DRIVE_ID
    // The Amiga drive-ID answer on RDY (HD spec §5.4). pio0, beside flux_out
    // and flux_in: 29 of its 32 instruction slots.
    bus_out_drive_id_init(pio);
    wf_logf(WF_INFO, "drive-id: answering DD 0x%08lx on DF0 motor-off selects",
            (unsigned long)DRIVE_ID_DD);
#endif
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

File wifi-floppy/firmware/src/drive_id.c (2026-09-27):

#include "drive_id.h"

// Each function is one path through floppy.pio's drive_id program; the
// comments name the instructions they stand for. Host-test-only: the device
// build does not compile this file (CMakeLists.txt) -- on the board the PIO
// program IS the behaviour, and this is its reference.

void drive_id_model_init(drive_id_model_t *m, uint32_t id) {
    m->id = id;
    m->shifter = 0;
    m->bits_left = 0;
    m->motor_on = true;      // the program starts at on_released: power-up is "motor was on"
    m->selected = false;
    m->level = false;        // X = 0
    m->rdy = false;
}

void drive_id_model_set_id(drive_id_model_t *m, uint32_t id) {
    m->id = id;              // instr_mem[reset_load], instr_mem[repeat_load] rewritten
}

void drive_id_model_select(drive_id_model_t *m, bool mtr_on) {
    m->selected = true;
    if (mtr_on) {                         // jmp pin falls through (MTR low): on_selected
        m->motor_on = true;
        m->rdy = m->level;                // mov pins, x
        return;
    }
    if (m->motor_on) {                    // jmp pin, reset_load: mov osr, <the ID>
        m->motor_on = false;
        m->shifter = m->id;
        m->bits_left = 32;                // ...and falls straight into id_bit
    }
    m->rdy = (m->shifter >> 31) != 0;     // id_bit: out pins, 1
    m->shifter <<= 1;
    m->bits_left--;
}

void drive_id_model_deselect(drive_id_model_t *m) {
    m->selected = false;
    m->rdy = false;                       // mov pins, null
    if (!m->motor_on && m->bits_left == 0) {   // jmp !osre falls through: repeat_load
        m->shifter = m->id;
        m->bits_left = 32;
    }
}

void drive_id_model_level(drive_id_model_t *m, bool assert) {
    m->level = assert;                    // exec'd `set x, level` (bus_out.c)
    // An assert while selected with the motor on also execs `set pins, 1`
    // (bus_out.c, at on_selected_wait); a release waits for the deselect's
    // `mov pins, null`.
    if (assert && m->selected && m->motor_on) m->rdy = true;
}

bool drive_id_model_rdy_gpio(const drive_id_model_t *m) {
    return m->rdy;
}

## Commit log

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2026-09-27 firmware: encode HD tracks on read in core0's loop; 25 KB SRAM track buffers; heap low-water log
    track_cache_get's only caller is main()'s core0 service loop (thread
    mode), so the ~4 ms encode runs there while the old track keeps
    streaming; start_streaming aborts it only once the new track is in
    hand, then repacks. All 160 tracks, through WFAD and the loader, match
    Greaseweazle's digests, asked out of order and with repeats as well as
    in order.
    The MFM-vs-HD decision reads only the slot the published token names,
    and the idle buffer is untagged before any fill, so a failed encode can
    never leave a stale (track, token) tag over torn bytes.
    The heap log counts only never-claimed space (__Sta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
    [main.c]
2026-09-27 firmware: heap low-water reads a break recorded by __wrap__sbrk, never calls sbrk from core0
    Review fix (Task 7, Critical 1): sbrk(0) from core0 was not a read. The
    SDK's _sbrk stores heap_end back even for an increment of 0, outside
    malloc's lock, while core1's mbedTLS/lwIP may be growing the heap -- a
    lost update corrupts it. Link with -Wl,--wrap=_sbrk; __wrap__sbrk calls
    the real one and records the new break (clamped to __StackLimit for
    PICO_USE_OPTIMISTIC_SBRK) in one aligned word, and heap_free_bytes()
    only loads it (`end` until the first growth). Disassembly: _sbrk_r ->
    __wrap__sbrk -> _sbrk, and nothing else calls _sbrk.
    Minors: the HD "new max" encode log moves after start_streamin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
    [main.c]
2026-09-27 firmware: PIO drive-ID answer on RDY, phase fixed (the reset select carries no bit); playsHd
    HD while an HD disk is mounted, DD otherwise; the word changes only at
    the start of an answer. RDY's level reaches the program by an exec'd
    `set x`, not its FIFO. WF_DRIVE_ID=OFF removes it and the playsHd claim.
    The model (drive_id.c) is host-test-only; the device build does not link
    it. pio0 holds flux_out 7 + flux_in 7 + drive_id 16 = 30 of 32.
    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
    [bus_out.c, drive_id.c, dskchg.c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]
2026-09-27 final-fix wave (feat/hd-floppies): bench-checklist gaps, HD-bytes-to-a-DD-only board, PIO/model drift, one slot in the swap block
    F1/F2/F3 (HANDOFF.md §3an): the bench prep now installs and proves 1.4.0 over
    USB before it is ever published to the release registry, so a phase or
    polarity bug in the drive-ID responder cannot reach a board over the air. A
    new checklist step covers a cold power-on with an HD disk already desired
    (the drive-ID responder answers DD until the disk is fetched over
    WiFi/TLS), and the existing HD-boot step is now labelled as the warm path.
    Two wording fixes: "no write: trk log line at all" (WPROT means the Amiga
    refuses before WGATE) and recording how long Copy takes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
    [main.c, test_drive_id_pio.c]
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2026-09-27 Add the 22 ohms resistor for the buzzer.
    [wifi-floppy_bom.csv, wifi-floppy_designators.csv, wifi-floppy_positions.csv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]
2026-09-27 Added double footprint for the buzzer (6.5 mm and 5 mm)
    [wifi-floppy_bom.csv, wifi_floppy.kicad_pcb, wifi_floppy.kicad_sch]
2026-09-27 HANDOFF 3an: bench -- HD drive ID never reached the wire (pio0 drops GP12's output enable); board on 1.4.0 with WF_DRIVE_ID=OFF; backlog: NFC swap card, PR #3 review
    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
2026-09-27 firmware 1.4.1: HD drive-ID answer reaches the wire (bench-proven design from bench/id-probe)
    Root cause of 1.4.0's dropped GP12 output enable: pico-sdk 2.3.0's
    pio_encode_mov(pio_osr, src) returns `mov pindirs, src` in release builds
    (pio_osr == pio_exec, remapped twice), so every HD reload switched RDY's
    output off. The two load words now come from drive_id_load() (drive_id.h),
    built from the MOV fields: HD 0xa0e2 `mov osr, y`, DD 0xa0eb
    `mov osr, ~null`. test_drive_id_pio.c pins the words and their OSR
    destination; run.sh fails on any pio_encode_mov(pio_osr in src/.
    drive_id (15 instructions, pio0 29/32): ID in Y (an SM restart clears
    ISR), MTR tested with `jmp pin`, clkdiv 10 so MTR set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
    [bus_out.c, drive_id.c, test_drive_id.c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]
2026-09-27 HANDOFF 3an: FIXED 2026-09-27 -- SDK encoder bug, PAL phase, bench results; README: HD verified on hardware (1.4.1)
    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
2026-09-27 drive-id fix round 1: honest bench status, a discriminating ID-select test, per-call SDK-encoder tripwire
    - README/HANDOFF §3an: the passing build was bench/id-probe 7565cea (pio2, pindir
    re-assert, Y reseed); 1.4.1 on pio0 without those has not run on hardware yet.
    §3an corrects "SM restart clears ISR": nothing restarts drive_id; that was the
    same mov-pindirs encoder bug.
    - test_drive_id.c: the "no CPU assert during an ID select" check uses HD's bit 30
    (0), so it fails if drive_id.c drops the motor_on guard (verified).
    - run.sh: flags every pio_encode_mov(pio_osr|pio_exec call (not _not/_reverse),
    per call, after stripping comments; survives set -e when nothing matches.
    - bus_ou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
    [bus_out.c, main.c, test_drive_id.c]
2026-09-27 adffs:verify: xdftool cross-checks HD disks both ways (as .hdf; amitools' ADF device is DD-only)
    Extends the independent xdftool cross-check to HD (3,520-block) disks:
    formatVolume({density:'hd'}) round-trips through xdftool's write/list/read
    in both directions (ours -> xdftool, xdftool -> ours), same as the existing
    DD checks, using HD_ROOT (1760) from readVolume's new rootBlock.
    The brief's mutation step (moving the bitmap to rootBlock+2) didn't fail any
    existing check: xdftool's list/write/info commands all follow the ROOT's own
    bitmap pointer wherever it leads, so a bitmap moved to the wrong block still
    looks fine to every read-based check. Added a real one: byte-diff our blank
    HD disk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
2026-09-27 browser: HD disks open and edit in the file browser; write-protect toggles like DD
    Task 6 of the HD writes plan: the file browser and every drive-chip/disk-row
    control now learn the root block from readVolume's own rootBlock (880 DD,
    1,760 HD) instead of a hard-coded ROOT_BLOCK, and HD disks follow the
    library's write-protect flag exactly like DD (HD writes spec §5.3) --
    WriteProtectToggle drops its `locked` prop entirely, and drive-chips.ts's
    DriveChipDisk.readOnly narrows to 'HFE' | null. hd-messages.ts now exports
    only HD_UNSUPPORTED; HD_NOT_BROWSABLE and HD_READ_ONLY, and the reasons
    hd_not_browsable/hd_read_only, are gone.
    Also folds in two small fixes from Task 5's review: mount-hd.t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
2026-09-27 firmware: decode 11 or 22 sectors by the mounted disk; verdict refuses the other density
    The HD fixture reader and 'prng' generator live in test/hd_fixture.h, shared
    by the HD firmware tests (controller ruling), not copied per test file.
    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
    [main.c, test_mfm.c]
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2026-09-28 firmware: WPROT follows the server's flag for HD too (the read-only term is gone)
    Task 12: write_back_wprot drops its fourth gate (an HD image forced
    read-only regardless of the server) now that Tasks 8-11 decode, store and
    upload HD writes; an HD disk asserts WPROT for the same three reasons a DD
    disk does -- nothing mounted, the server's flag, or the uploader's force.
    main.c's WPROT computation, its log line and the "FOUR gates" comment
    follow; the stale drive-ID comment claiming a shared HD derivation with
    write_back_wprot is corrected, since that derivation is now the drive-ID
    check's alone.
    Also folds in three loose ends from Task 11's review: uploader.c's
    up_read_whole_track comment n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
    [main.c]
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2026-09-28 Final review fixes: the close never hashes a store in progress; decode time in the write log
    F1: g_write_gen is now a seqlock. core0 makes it odd before the store's
    first byte (write_back_gen_begin) and even after DIRTY and last_ms
    (write_back_gen_end), DD and HD alike; up_close refuses an odd g0 and any
    g1 != g0, with fences on both sides. Before, a store that began before the
    close read the generation and was still copying at the re-check left both
    reads equal and nothing dirty, so the close went out over a half-written
    track (409 mismatch, up_server_wins, the write lost). Host tests: a DD
    store torn at a sector boundary (decodes cleanly) and an HD store half
    copied, begun before the close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
    [main.c]
2026-09-28 HANDOFF 3ao: HD writes merged and on the bench board; steps 1-2 pass, step 3 lost one track to a WDATA glitch
    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
2026-09-28 write: count WDATA glitches (< 3,000 ns) per capture, log as `short <N>`
    Diagnostic only -- decoding is unchanged. Adds flux_capture_result_t.glitches,
    counted in flux_capture.c's consume() right where ns_min/ns_max are (same
    reset-per-capture semantics), against a shared FLUX_GLITCH_NS threshold and
    flux_ns_is_glitch() predicate in flux_bits.h so the host test exercises the
    exact function production code calls, not a re-implementation.
    The `write: backlog ... ns %u-%u cells %u/%u/%u` log line gains ` short <N>`;
    everything before it is byte-identical to earlier logs. This is what rev B's
    bench retest of the 2026-09-27 1,640 ns WDATA glitch (HANDOFF 3ao step 3)
    should read: must be 0.
    Firm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
    [main.c]
2026-09-28 Create disk: a New disk panel with Size and Filesystem switches
    Replaces the four-item Create ADF menu with a small form: Size
    (880 KB | 1.76 MB), Filesystem (FFS | OFS), each with a one-line hint,
    and a Create button. A popover on desktop, a bottom sheet under 640 px.
    Both switches reset to 880 KB / FFS every time the panel opens, so a
    choice never carries to the next disk.
    e2e: createAdf() clicks through the panel; new test for the reset; the
    phone test now checks the sheet sits at the bottom, fits 390 px and has
    44 px targets.
    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
2026-09-28 next-disk: the pure rule and its org-scoped loader
    Adds nextDisk/boardHolds/readNextForDevices/nextInfo (multi-disk spec §2)
    plus currentDiskId, a small pure helper so a second tap during a swap
    counts from the WANTED disk, not the mounted one.
    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
2026-09-28 nfc: arm a Next-disk card write; a cancel resets the kind
    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
2026-09-28 fix: correct measured worst-case poll body comment (1384 bytes, not 1352)
    Review round 1 finding: the comment cited a number computed by hand
    outside the test rather than measured from the actual test string.
    Re-measured by temporarily forcing the assertion to fail so its message
    printed the real `worst` value: 1384 bytes against the 1536-byte
    DC_POLL_BODY_BYTES buffer (152 to spare), not 1352/184. The assertion
    itself was already correct and unaffected; only the comment was wrong.
    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
2026-09-28 firmware: extract nfc_arm_write's gating prefix into arm_gate
    Review finding: nfc_arm_write_next duplicated nfc_arm_write's gating prefix
    verbatim. That gate is what stops a write landing on a tag already on the
    reader, so the two must never drift apart. Extracted into a static
    arm_gate(r, seq) helper called by both; each function now only sets its own
    payload, armed and arm_bad. Behaviour unchanged.
    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
2026-09-28 firmware: preload the next disk into the idle slot; swap from it; tap next
    Multi-disk Next disk, Task 11 (spec 2026-09-28 §4.2-4.5):
    - dc_take_next lifts the poll's `next` object (blanking it) before
    dc_handle_poll_body reads the flat sha256/diskId keys; next:null drops
    the preload record.
    - dc_fetch_image split into dc_fetch_into (request, stream, verify, never
    publish) plus the publish; every regular fetch drops the preload record
    first, since it overwrites the idle slot.
    - dc_preload_step fetches `next` into the inactive slot without publishing,
    only when idle and the new preload gate (dc_set_preload_gate) allows.
    - Swap from preload: after the hold check, publish the preloaded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
2026-09-28 firmware 1.6.0: Next-disk card taps, preload loop, OLED lines
    - nfc_ui_next_line: "Next: disk N of M" / "Saving, then disk N" /
    "Next: single disk" / "Next: no disk"; tap_line names SINGLE/NO_DISK.
    - NFC_EV_TAG_NEXT -> dc_tap_next; "saving" uses the preload gate's own
    writes_outstanding predicate.
    - nfc_wreq_t carries `next`; core0 arms nfc_arm_write_next, title
    "Next-disk card". A disarm is unchanged.
    - Preload gate: no dirty/open/parked uploader session, no held swap
    (up_holds), no fw update QUEUED..REBOOTING. dc_preload_step runs once
    after a real idle poll with no NFC work waiting; its state feeds the
    existing backoff/halt chain, and it owes a status report.
    - OTA idle also r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
    [main.c]
2026-09-28 firmware: Next-disk "Saving" follows the swap hold (up_holds), not the preload gate
    A parked uploader released the hold, so the swap went ahead while the OLED
    said "Saving, then disk N". writes_outstanding stays the preload gate's.
    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
    [main.c]
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2026-09-28 firmware: WPROT and the mount report before any preload; a tap interrupts a preload
    Final whole-branch review, firmware items:
    C1: the preload ran before Item 3 (WPROT) and Item 4 (the mount report),
    so a swap published by dc_step left WPROT showing the PREVIOUS disk's
    protection for a whole ~5 s preload, after core0 had already raised CHNG.
    The preload now runs after Items 3 and 4, and not at all while the mount
    is still unreported. Its result still replaces `s` for the backoff/halt
    chain; a changed preload record is reported right after it (never ahead of
    a waiting tap), or by a later Item 4.
    I1: dc_preload_step installs the poll-interrupt for its transfer. An
    interrupted preload leaves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
    [main.c]
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2026-09-28 next disk: a preload line that is never falsely "loading"; chip and card fixes
    Final whole-branch review m7, m1, m2 (and the e2e half of I2):
    m7: nextInfo's preload is 'ready' (state ready AND the next disk's sha),
    'loading' (state loading), 'waiting' for anything else a 1.6.0+ board
    reports ("Disk N not preloaded yet"), or null (hidden). 'none' and a stale
    ready record used to read "loading...", which could stay false forever.
    One preloadText wording for both render sites.
    m1: the chip's preload line is a plain div, not a second menu group label.
    m2: the card's preload line is gated on converged, like its Next button.
    e2e: the preload spec covers the waiting state; the Next-card write test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
2026-09-28 e2e: the mobile Next-card board reports preload, as a 1.6.0+ board does
    Follows the I2 fix: the Devices page offers the Next-disk card only on
    boards that report `preload`, so this test's simulated board must too
    (the same change the review asked for in next-disk.spec.ts test 7).
    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
2026-09-28 HANDOFF 3ap: fw 1.6.0 confirmed on the board; card swap on a two-disk title passes
    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
2026-09-28 fix(disk sets): pin renumbers, number a suggested set from 1, undo keeps the arrangement
    - m4: every disk UPDATE is pinned to the title the plan read it in
    (Renumber.fromGameId), so a concurrent tab's move is not pulled back.
    - m2: a rename (the suggestion path) plans with { compact: true }: the
    target's own disks and the incoming ones are numbered 1..N, so a lone
    target TOSEC-numbered "Disk 2" no longer starts the set at 2.
    - I4: the undo snapshot carries diskOrderSource and the recreated title
    gets it back; sortTitle is no longer taken from the client but derived
    with makeSortTitle(title). A pre-change snapshot still parses (sortTitle
    stripped, diskOrderSource defaults to null)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
2026-09-28 fix(ingest): never add an upload's disks to a human-arranged set (I1)
    A set keeps its target title's original stableId('game', org, sortTitle,
    year), so a later upload parsing to the same title/year joined the set at
    its parsed number (a patched Install3_1_4.adf became a second "disk 1").
    When that game id exists with disk_order_source = 'human', each such disk
    now goes to a fresh one-disk title beside it (stableId(..., 'beside-set',
    sha256), metadataSource 'filename'). A re-send of a disk already there
    stays the no-op it was (an HFE re-send still gets its format flip, as a
    plain guarded UPDATE that can never insert). Ordinary titles unchanged.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
2026-09-28 fix(upload): suggestion name fits the route, errors read as sentences (I3)
    - The name input takes at most 80 characters (the route's rename cap),
    and a longer suggested name is cut to 80 before it is shown.
    - A shared-folder suggestion is named after the LAST folder only, not the
    whole relative parent path; folders are still compared by full path.
    - Error codes are worded in plain text via one mapping now shared with the
    Add disks dialog (src/lib/disk-set-errors.ts). same_title / not_found
    mean the disks moved on meanwhile: the page refreshes, the panel goes,
    and the toast says "The disks changed while you were deciding — reloaded".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
2026-09-28 fix(disk sets): deleting a disk from an arranged set closes the gap (m1)
    Deleting a middle disk of a title left "Disk 3 of 2". When the title is
    human-arranged, its remaining disks are renumbered 1..N (relative order
    kept) in the same batch as the delete, and boards holding them get the new
    game/number through disk-set-store's applyPlan: only *_game_id/*_disk_no,
    guarded on the disk the board still names, never *_disk_id or
    desired_version. The title delete for a last disk now also carries the
    NOT EXISTS (no disks) guard, and reports gameDeleted from what it removed.
    Claude-Session: https://claude.ai/code/session_01UNftEdm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
2026-09-28 fix(disk sets): a device follows a disk only if the disk really moved; neutral invalid_body text
    - applyPlan: each device UPDATE (desired and mounted) now also requires
    EXISTS a disk with that id at the planned game_id and disk_no. A disk
    UPDATE pinned to fromGameId (m4) matches nothing when another tab moved
    the disk; the board is then no longer told this plan's title/number.
    Sound because the batch runs in order as one transaction. Applies to
    disk-delete's gap-closing too.
    - invalid_body is shared with the Add disks dialog, which sends no name:
    worded neutrally now.
    Claude-Session: https://claude.ai/code/sess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
2026-09-29 fix(disk sets): an unchanged set name is not a human edit; neutral error text
    addDisksToSet with a rename equal to the target's current title now
    writes only disk_order_source (still numbering the set from 1), so a drop
    or upload suggestion that keeps the prefilled name no longer freezes a
    TOSEC/OpenRetro/Demozoo-identified title against later corrections.
    requireGame returns the title for the comparison.
    same_title / nothing_to_add read neutrally ("Those disks are already in
    this set." / "There were no disks to add."). The drop dialog says the
    dragged title's cover, Demozoo link and collection memberships go with
    it. The rename e2e waits for the DB before the refreshed heading.
    Co-Authore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
2026-09-29 feat(disk sets): zoneOf and the centre-arm state machine for folder-style drops
    A pure module: a card's centre is the middle 50% x 60% of its slot, the
    pointer arms that centre after 300 ms, and a drop resolves to set / none /
    reorder. Wired into the collection view in the next commit.
    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
2026-09-29 feat(disk sets): folder-style drops in a collection -- centre adds, edges reorder
    Replaces feat/set-dwell's hold-anywhere dwell, whose target slid out from
    under the pointer while it waited. The collision detection now tags the
    pointer's droppable with its zone, measured against the droppable's
    transform-agnostic rect. While the pointer is in a card's centre no card
    moves (a null sorting strategy); after 300 ms the card arms and a drop opens
    the set dialog. A drop in a centre before it arms does nothing; an edge drop
    reorders exactly as before. Unfiltered views, rail drops and rail reorder are
    unchanged.
    Claude-Session: ht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
2026-09-29 test(e2e): folder-style drops in a collection, walked at a hand's pace
    Replaces the three feat/set-dwell tests. Every drag walks in 4 px steps a
    frame apart and holds for real. The target's box is measured at every step
    and through a 600 ms hold: within 2 px of its slot from the first step in
    its centre (and, walked straight in, never moved at all). Also: left and
    right edge drops reorder with no hint, a rest in an edge then the centre
    brings the card back under the pointer and Cancel leaves everything, and a
    drop in a centre before it arms writes nothing.
    Claude-Session: https://claude.ai/code/session_01UNftEdmHHNsd183Jnm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
2026-09-29 fix(disk sets): a previewed card's slot is all edge; an inward creep is not a rest
    Review fixes. (1) Once a card's reorder preview shows, its whole slot counts
    as edge until the pointer leaves it, so aiming at the middle of the gap it
    left reorders instead of snapping it back and refusing the drop. (2) Rest
    also requires the pointer not to creep more than 2 px closer to the card's
    middle, so a very slow approach (1 px / 30 ms) never starts a preview; a
    pure speed threshold that strict would demand a motionless finger. (3) A
    drop on the armed card makes the set even if the last frame drifted into the
    edge. (4) The target glides back like its neighbours: the instant snap was
    only for entering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
2026-09-29 collection-provider: track the dragged card while set-drop is open
    Adds pendingSetDrop to the collections context: the id of the card
    that was dragged into a "make a disk set" drop, and whether it is
    fading back into view after a close without success. Set the instant
    the dialog opens (so game-grid.tsx can hide the card before dnd-kit's
    own drop animation flies it back to its slot), flipped to "returning"
    on Cancel/Escape/backdrop, and reset on a fresh drag or once
    router.refresh() has landed new game ids.
    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
2026-09-29 game-grid: hide the dragged card while set-drop is open
    Reads pendingSetDrop from the collections context and, on the one
    card it names, replaces the usual drag style with visibility/opacity
    overrides: hidden with no transition the instant the dialog opens
    (the card's slot keeps its space, its sibling's box does not move),
    and a 200ms opacity fade back in when pendingSetDrop.returning is set
    (Cancel, Escape, the backdrop). aria-hidden follows the same flag so
    the hidden card is not announced or focusable meanwhile.
    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
2026-09-29 fix(firmware): release a disk only when the Amiga has finished with it (1.6.1)
    A Next-disk tap during a save swapped Locale out after the upload closed
    but before AmigaDOS wrote the file header; the directory pointed at block
    597, which never arrived. The swap hold now also waits for the Amiga to be
    idle: motor off, WGATE clear, 3 s without write activity (20 s of no write
    activity releases regardless). Held polls are paced at 500 ms.
    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
    [main.c, swap_gate.c, test_swap_gate.c]
2026-09-29 fix(firmware): the motor switching on counts as activity for the swap hold
    Review I1: measured from writes alone, the 20 s force released a disk
    during a fresh save's read-before-write phase. Also: the panel's query no
    longer logs, an interrupted poll keeps the hold state, held polls pace 1 s.
    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
    [dskchg.c, main.c, swap_gate.c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]
2026-09-29 fix(firmware): read the motor flag before its time, so the swap hold never sees on-with-an-old-time
    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
    [main.c]
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

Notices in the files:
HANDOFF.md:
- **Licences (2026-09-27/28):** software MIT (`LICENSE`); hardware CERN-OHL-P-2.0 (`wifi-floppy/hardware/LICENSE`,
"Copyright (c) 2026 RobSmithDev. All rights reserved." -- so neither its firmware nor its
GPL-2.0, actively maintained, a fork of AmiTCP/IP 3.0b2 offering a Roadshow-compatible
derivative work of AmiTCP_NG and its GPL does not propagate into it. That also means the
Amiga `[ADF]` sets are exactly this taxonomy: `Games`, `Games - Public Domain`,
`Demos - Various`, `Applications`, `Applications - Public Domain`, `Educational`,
